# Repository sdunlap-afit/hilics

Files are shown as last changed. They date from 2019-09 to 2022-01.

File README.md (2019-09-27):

<div>
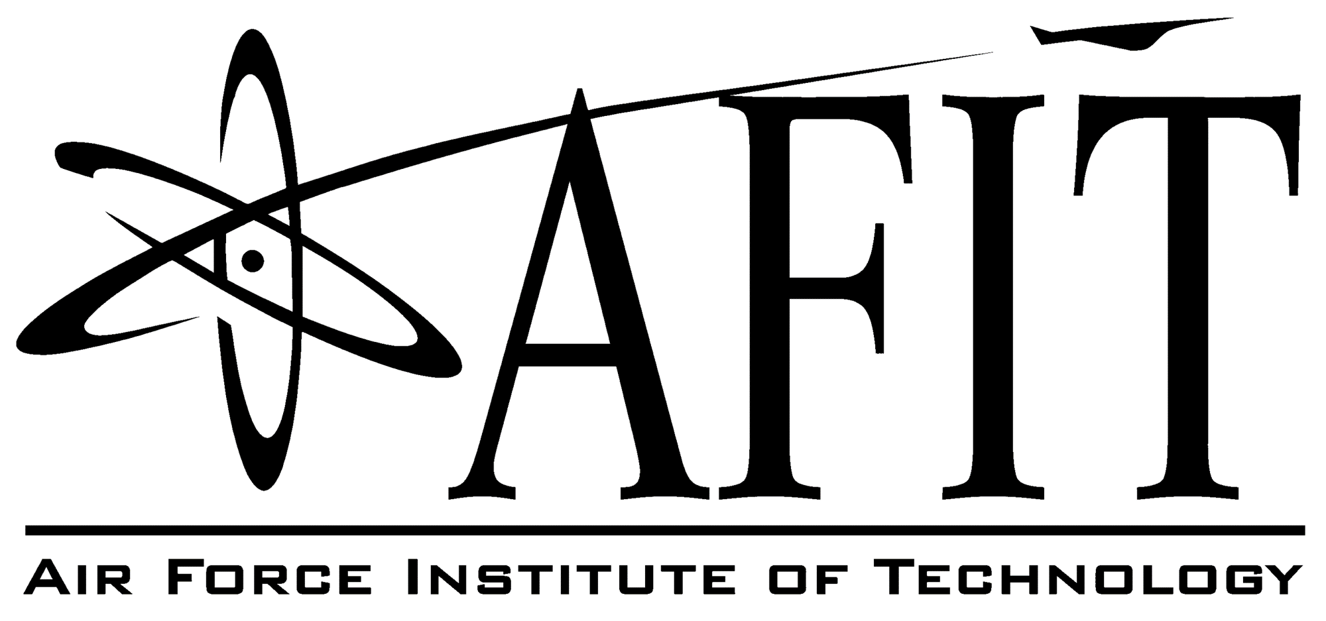
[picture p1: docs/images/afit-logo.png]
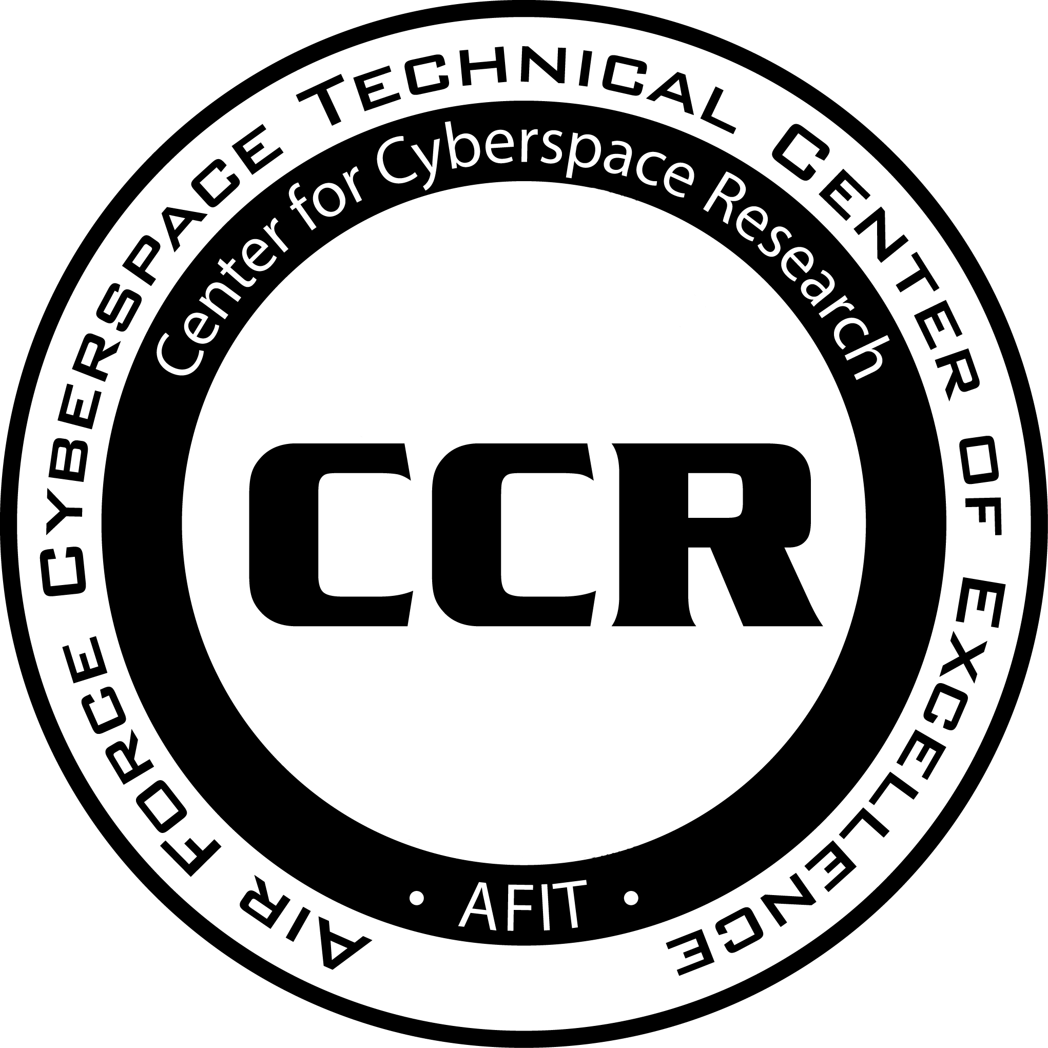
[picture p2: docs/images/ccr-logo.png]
  
</div>
<br clear="all" />
<br>

<div align="center">
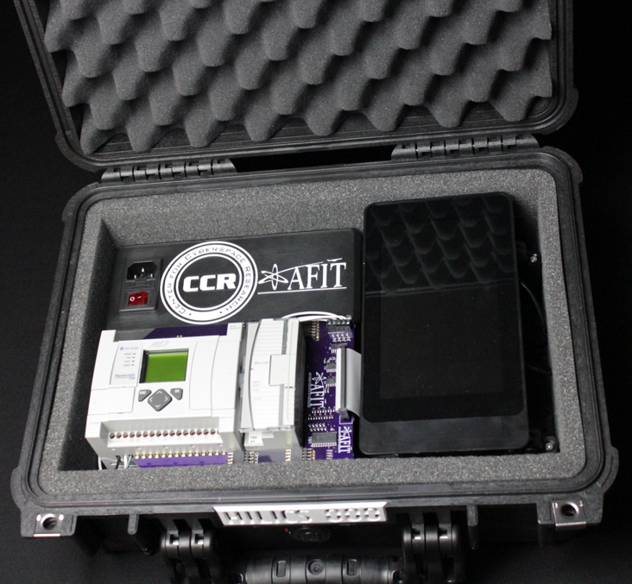
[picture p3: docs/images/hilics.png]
HILICS

</div>

# HILICS - Hardware-in-the-loop industrial control system training platform

The Center for Cyberspace Research (CCR) has conducted extensive research in Industrial Control System (ICS) security. ICS architectures utilize a variety of proprietary hardware and software configurations to control and monitor industrial processes and safety systems. Defenders must be familiar with the functionality, requirements and limitations of control systems in order to successfully defend them from cyber-attacks. Hands-on training and experience is crucial for defenders who must be able to interact safely with a given control system. Without this experience, defenders could mistakenly take actions that cause more harm to the system than a basic cyber-attack.  

Given the physical nature of ICS architectures, training platforms can be difficult and costly to develop. To address this, the CCR has developed HILICS - a unique hardware-in-the-loop ICS platform designed to support training, education and research. HILICS utilizes a MicroLogix 1100 Programmable Logic Controller (PLC) to introduce students to PLC operating basics and the associated programming languages. This PLC is a low-cost commercial product that provides a representative set of features to give students exposure to control system functionality. The HILICS platform is a custom hardware-in-the-loop system that enables trainers to incorporate multiple physical process simulations and expose students to a range of control system applications. The platform is designed to be flexible and scalable, allowing for varying class sizes and supporting various control system applications.  

# How it works

HILICS is a hardware-in-the-loop training system. A Raspberry Pi provides simulations of physical processes such as fluid tanks or garage doors. Each simulation is made up of sensors, actuators and physical components such as pipes or tanks. **The Raspberry Pi does not have any network connection to the PLC.**

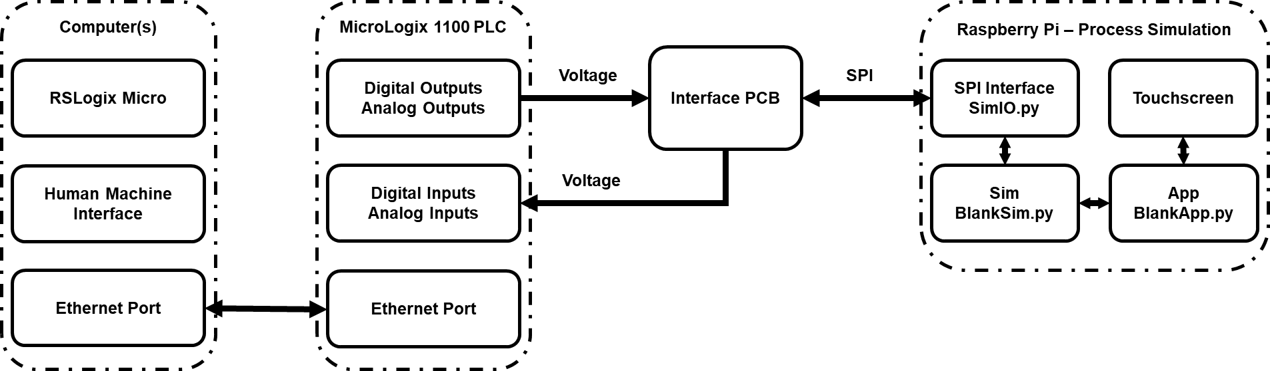
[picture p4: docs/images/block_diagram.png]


We will use the tank simulation as an example.

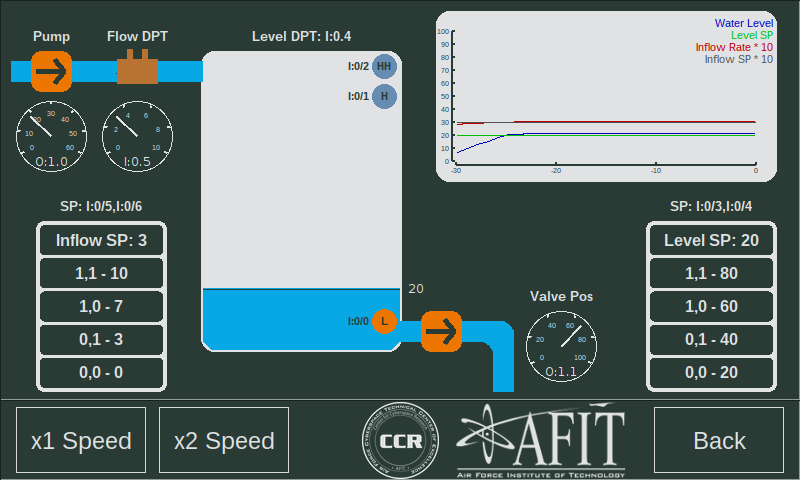
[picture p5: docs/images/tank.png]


## Sensors

The Raspberry Pi simulation determines the current state of the process and calculates the values of the simulated sensors. The sensor values are sent to the PLC via the interface PCB. The PLC receives these values as voltages using it's digital and analog inputs. The PLC's ladder logic program determines how the PLC responds to the sensor values.

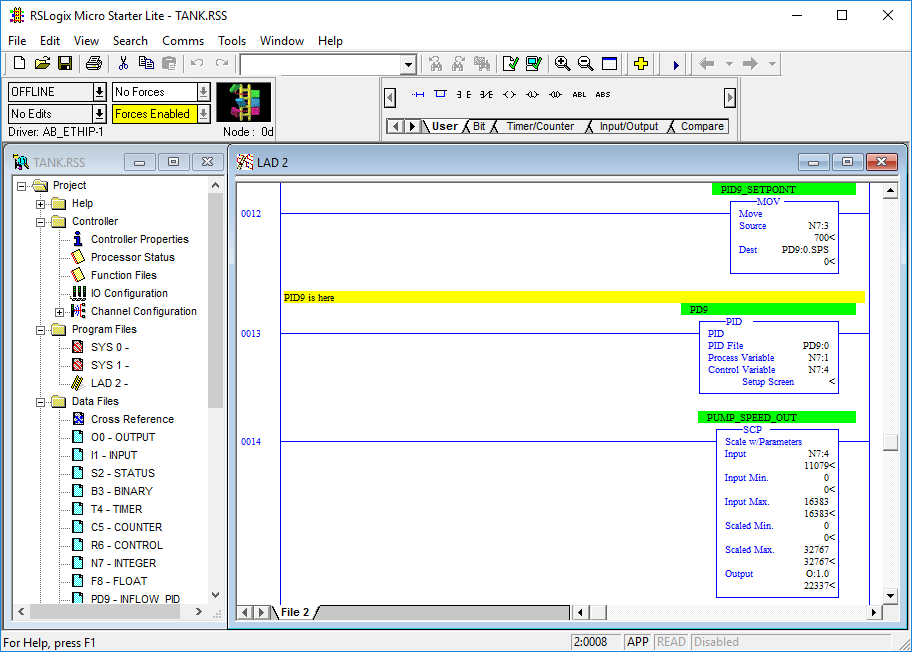
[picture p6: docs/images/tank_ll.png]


For the tank, there are two analog sensors and three digital sensors.

* Analog Sensors:
	* Inflow differential pressure transmitter.
	* Fluid level differential pressure transmitter.
* Digital Sensors:
	* Low level float
	* High level float
	* High-High level float
* Other:
	* This simulation was designed to work without the presence of an HMI. Typically, an HMI would be used to select set points for the process.
	* The Inflow SP button panel uses two of the PLC's digital inputs to send the desired inflow rate to the PLC.
	* The Level SP button panel uses two of the PLC's digital inputs to send the desired fluid level of the tank to the PLC.

## Actuators

The PLC reads the values of the sensors, compares them to the desired values and then adjusts it's outputs (as voltages) to control the actuators. The Raspberry Pi receives these values via the interface PCB and adjusts the simulation appropriately. 

For the tank, there are two analog actuators.

* Pump - the speed of the pump is used to calculate the current inflow rate into the tank.
* Valve - the position of the valve is used to calculate the outflow rate draining from the tank.

While the tank only has analog actuators, an example of a digital actuator is an indicator light controlled by the PLC's digital outputs.

Find further details about this simulation [here.](../labs/L3_Tank_Control.md)

# What's Included

## Documentation

The [docs](./docs) folder contains various documents including a bill-of-materials, hardware assembly and computer setup instructions.

## Source code

This repository contains all of the Python [source code](./src) you need to get started. The [apps](./src/apps) folder contains the following Applications:

* [IO_Test.py](./src/apps/IO_Test.py) - Basic app to test the functionality of the HILICS kit.
* [Door.py](./src/apps/Door.py) - Garage door simulation.
* [Fluid_Tank.py](./src/apps/Fluid_Tank.py) - Fluid tank with two control loops.
* [Blank_App.py](./src/apps/Blank_App.py) - A template to help you get started writing your own app.
* [Test_App.py](./src/apps/Test_App.py) - An app you can enable and edit to test your display elements during development.

## Hardware

The [hardware](./hardware) folder contains the design files and stl files you need to 3D print the frame for HILICS.

The [eagle](./hardware/eagle) folder contains all of the PCB design files and BOM.

## Labs

HILICS was designed for use in cyber security education, but the labs released here only cover basic PLC operations. Future labs may cover cyber concepts. 

The [labs](./labs) folder contains three basic labs to get started.

* [Lab 1](./labs/L1_Setup.md) - Get connected to your PLC and start programming in ladder logic.
* [Lab 2](./labs/L2_Door_Control.md) - Write a ladder logic program to control a garage door simulation.
* [Lab 3](./labs/L3_Tank_Control.md) - Learn the basics of PID control and PID tuning.

# Getting Started

## [Read the docs](./docs/README.md)

## [Try the labs](./labs/README.md)

## Contribute

This repository is not currently maintained and we will not be accepting any pull requests. If we develop any additional capabilities, we will release them here. If enough interest is shown, we might begin actively maintaining the repository. 

If you would like to contribute, look at the existing forks, or feel free to start your own.

# Disclaimer

Note that the views expressed in this project are those of
the authors and do not reflect the official policy or position of
the U.S. Air Force, U.S. Department of Defense or the U.S.
Government.

Approved for public release, 24 Sep 2019, Case #88ABW-2019-4607.

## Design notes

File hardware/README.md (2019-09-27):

<div>
HILICSHILICS  
</div>
<br clear="all" />
<br>

# Custom Hardware

## [Interface PCBs](./eagle/ML1100_Pi_Interface)

For each HILICS kit, you will need one each of the five [Interface PCBs](./eagle/ML1100_Pi_Interface). The bill of materials is in the folder with the PCBs. The BOM is for Digikey but provides specifications if you want to source components from a different supplier.

**You will also need 40-pin male headers for the Raspberry Pi ribbon cable to connect to the main PCB. These are cheaper on Amazon.**

If you plan to solder these by hand, make sure you are competent with surface mount soldering techniques. It may also be helpful to modify the main PCB design to use resistor arrays instead of individual resistors. Similar modifications can help reduce the amount of soldering required.

## [3D printing](./cad/stl_files)

The frame was designed in sections so that the largest part (135mm x 210mm) would still fit on a smaller 3D printer. 
We printed all of our components using black PLA without any supports. 
The amount of time and filament it will take depends heavily on your 3D printer settings.

 Our settings:

* 0.4mm layer height (0.2mm first layer height)
* 0.6mm nozzle
* 2 perimeters
* 3 bottom layers
* 3 top layers
* 20% infill

You will need to 3D print the following stl files (quantities listed):

* 1x - PLC Frame - 1x_HILICS_PLC_Frm.stl
* 2x - Raspberry PI Frame - 2x_HILICS_Pi_Frm.stl
* 2x - PCB legs - 2x_PCB_Leg.stl
* 3x - Extension Blocks - 3x_HILICS_ExtBlck.stl
* 1x - Choice of power box:
	* Multi-color: HILICS_Power_Color_* are individual stl files for multi-extruder/multi-color printers.
	* Single-color: HILICS_Power_single_ext.stl is for single extruder/color printers.

If you need to make modifications to the design, the Fusion 360 design files are [here.](./cad/Fusion360)

## [Nameplates](./cad/Nameplates)

You may also want to print [nameplates](./cad/Nameplates) for the front of your Pelican cases to uniquely identify each HILICS kit. We printed ours in white PLA

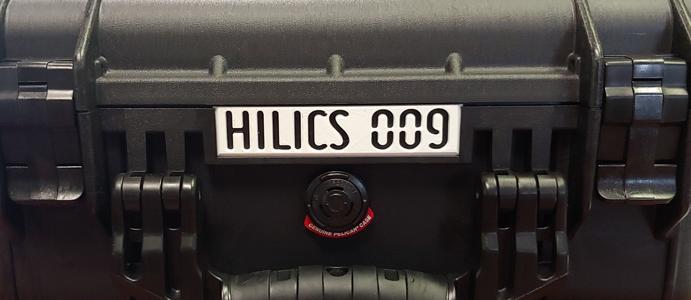
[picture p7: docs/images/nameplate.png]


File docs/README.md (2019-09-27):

<div>
HILICSHILICS  
</div>
<br clear="all" />
<br>

This guide will walk you through the steps to build your own HILICS training platform.

**WARNING: Building a HILICS kit is not for the faint-of-heart. Each HILICS kit costs roughly 1,000 USD to make (not counting labor), but your costs will vary. You will need to 3D print the frame, fabricate and solder the PCBs, wire 110 VAC power to the PLC, and setup a Raspberry Pi running Rasbian.**

# Components - BOM

## MicroLogix 1100 PLC
HILICS is designed to work with the MicroLogix 1100 PLC. The specific model number for the PLC and the Analog Output module are listed below. 

**NOTE: HILICS does not currently support any other PLC or PLC configuration. Other versions of the MicroLogix 1100 may work, but modifications will be needed.**

* 1763-L16BWA - MicroLogix 1100 with:
	* 9 digital inputs
	* 6 relay outputs
	* 2 analog inputs
	* 110 VAC power input

* 1762-OF4    - Module with 4 analog outputs

## [Raspberry Pi](https://www.raspberrypi.org/)

HILICS is designed around the Raspberry Pi for running process simulations.

For each HILICS kit, you will need the following Raspberry Pi components:

* Raspberry Pi from the list below.
* Official Raspberry Pi 7" touch screen display.

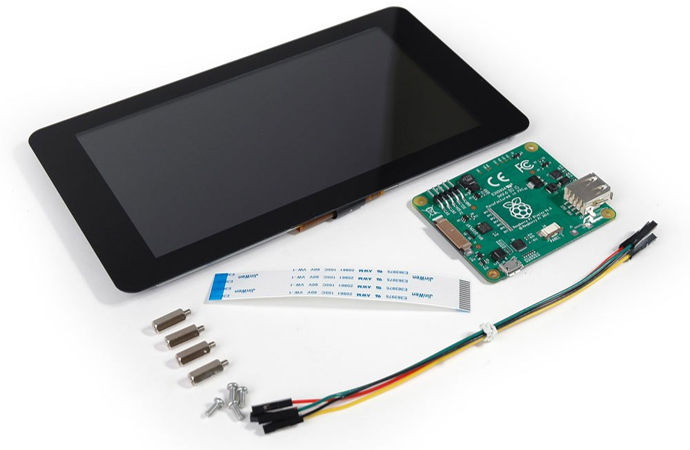
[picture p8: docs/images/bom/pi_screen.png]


* SmartiPi case for the official Raspberry Pi 7" touch screen Display.

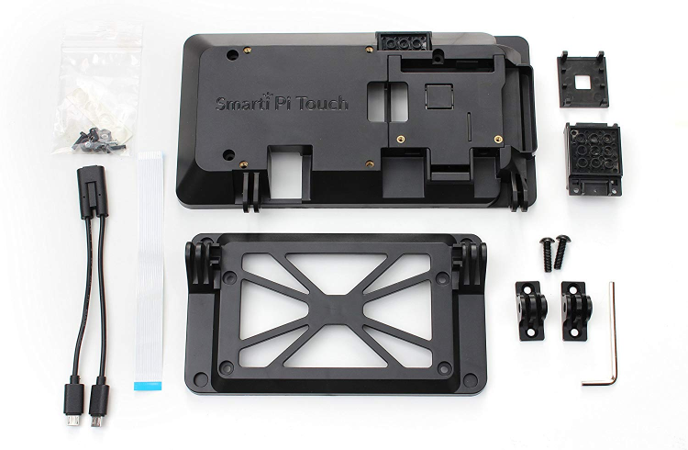
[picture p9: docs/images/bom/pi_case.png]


* 40-pin (2 row) male header (for main HILICS PCB).
* The following components may come as part of a Raspberry Pi kit (e.g., CanaKit)
	* 40-pin GPIO ribbon cable for Raspberry Pi.
	* Micro SD card.
	* Raspberry Pi power supply (5V 2.5A).
	* Optional, but recommended - Raspberry Pi heatsinks

Tested:
* Raspberry Pi 3 B 
* Raspberry Pi 3 B+

Untested, but should work:
* Raspberry Pi 4

Not recommended
* Raspberry Pi 2 or prior
* Raspberry Pi Zero or similar

## [Pelican 1450](https://www.pelican.com/us/en/product/cases/protector/1450)

The HILICS frame was designed to fit inside a Pelican 1450 case with the "Pick N'Pluck" foam removed.

Other cases may work (with modifications), but we recommend you look at the dimensions in the Fusion 360 files before purchasing a case.

## Power connectors

These are generic parts that are cheap and readily available. Purchase one to verify it will fit in the 3D printed power box. If the power box is too tight, you may need to use a knife to trim away some plastic.

Each HILICS kit requires:
* One 110 VAC panel mount outlet
* One panel-mount power socket with fuse and switch

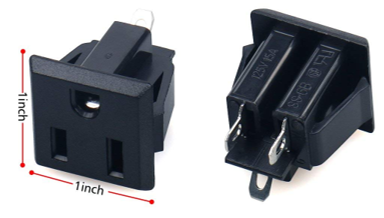
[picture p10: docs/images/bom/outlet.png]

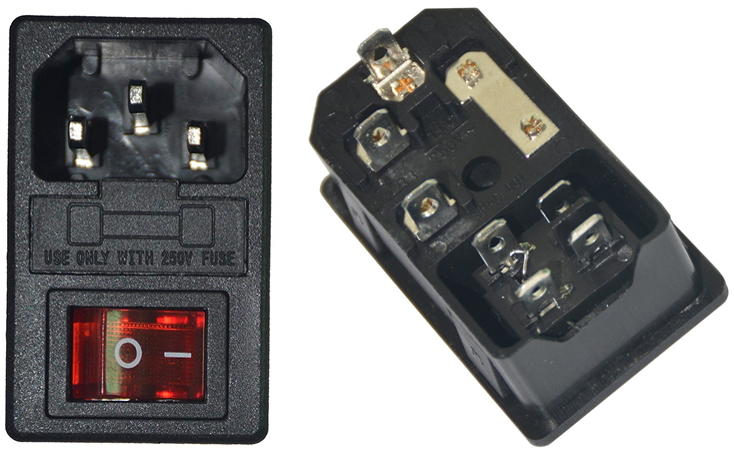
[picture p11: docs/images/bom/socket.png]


## Other components

* M3x8mm countersunk bolts/screws.
* M3x12mm countersunk bolts/screws.
* M3x10mm pan head bolts/screws (longer will also work).
* M3 nuts.
* M4x8mm pan head bolts/screws (longer will also work).
* 22 AWG stranded wire.
* 18 AWG stranded wire.
* Spade connectors, strippers and crimpers

## [Interface PCBs](../hardware/eagle/ML1100_Pi_Interface)

For each HILICS kit, you will need one each of the five [Interface PCBs](../hardware/eagle/ML1100_Pi_Interface). The BOM is in the folder with the eagle files. The BOM is for Digikey but provides part numbers if you want to source components from a different supplier.

**You will also need 40-pin male headers for the Raspberry Pi ribbon cable to connect to the main PCB. These are cheaper on Amazon.**

If you plan to solder these by hand, make sure you are competent with surface mount soldering techniques. It may also be helpful to modify the main PCB design to use resistor arrays instead of individual resistors. Similar modifications can help reduce the amount of soldering required.

## [3D printing](../hardware/cad)

The frame was designed in sections so that the largest part (135mm x 210mm) would still fit on a smaller 3D printer. We printed all of our components using black PLA without any supports. 
The amount of time and filament it will take depends heavily on your 3D printer settings.

 Our settings:

* 0.4mm layer height (0.2mm first layer height)
* 0.6mm nozzle
* 2 perimeters
* 3 bottom layers
* 3 top layers
* 20% infill

You will need to 3D print the following stl files (quantities listed):

* 1x - PLC Frame - 1x_HILICS_PLC_Frm.stl
* 2x - Raspberry PI Frame - 2x_HILICS_Pi_Frm.stl
* 2x - PCB legs - 2x_PCB_Leg.stl
* 3x - Extension Blocks - 3x_HILICS_ExtBlck.stl
* 1x - Choice of power box:
	* Multi-color: HILICS_Power_Color_* are individual stl files for multi-extruder/multi-color printers.
	* Single-color: HILICS_Power_single_ext.stl is for single extruder/color printers.

If you need to make modifications to the design, the Fusion 360 design files are [here.](../hardware/cad/Fusion360)

## [Nameplates](../hardware/cad/Nameplates)
You may also want to print [nameplates](../hardware/cad/Nameplates) for the front of your Pelican cases to uniquely identify each HILICS kit. We printed ours in white PLA



# Assembly

## [Raspberry Pi setup](./RPi_Setup.md)

## [Hardware assembly](Hardware_Assembly.md)

## PLC setup

1. [Install Rockwell Tools](./Rockwell_Tools.md)
1. [Configure PLC network settings](./PLC_Net_Config.md)
1. [Configure RSLinx](./RSLinx_Config.md)
1. [Configure RSLogix project](./RSLogix_Net_Config.md)

## [Hardware test](./Hardware_Test.md)

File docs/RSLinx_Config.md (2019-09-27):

<div>
HILICSHILICS  
</div>
<br clear="all" />
<br>

# RSLinx setup 

RSLinx is a utility that facilitates communication between RSLogix Micro and Rockwell PLCs. In order for RSLogix to talk to the PLC, RSLinx must first be configured.

**Before you begin this guide, make sure that [RSLinx is installed](./Rockwell_Tools.md) and that you can ping the MicroLogix 1100.**

1. Open RSLinx and click the RSWho icon.

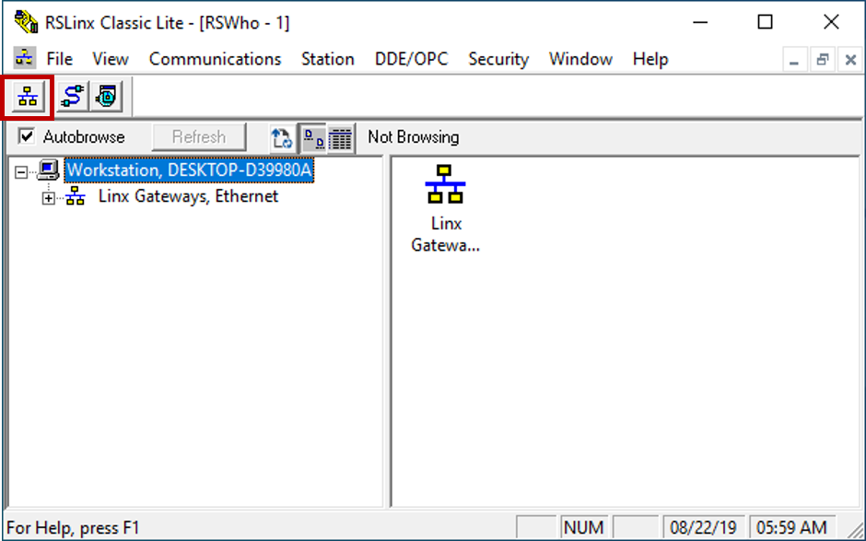
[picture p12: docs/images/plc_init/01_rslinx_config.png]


2. Click "Communications >> Configure Drivers..."

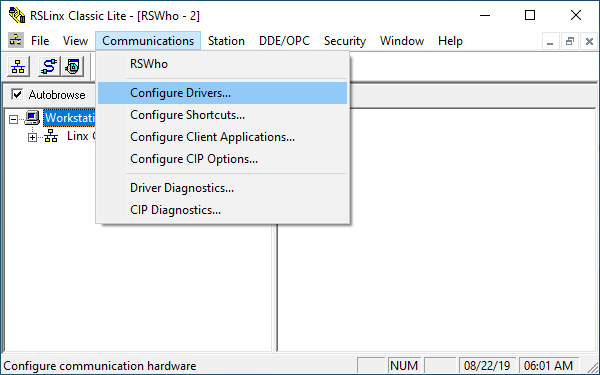
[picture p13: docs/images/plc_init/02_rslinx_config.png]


3. In the Configure Drivers window, select "EtherNet/IP Driver" from the dropdown menu.

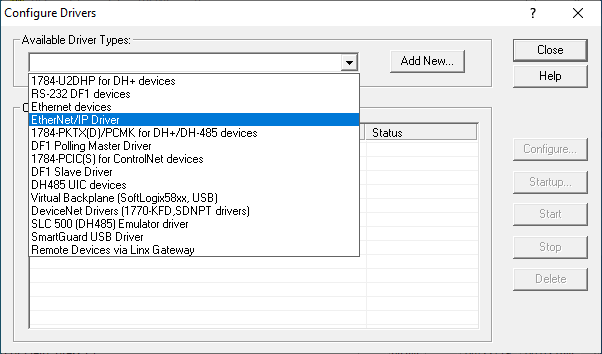
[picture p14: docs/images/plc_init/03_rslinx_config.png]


4. Click "Add New".

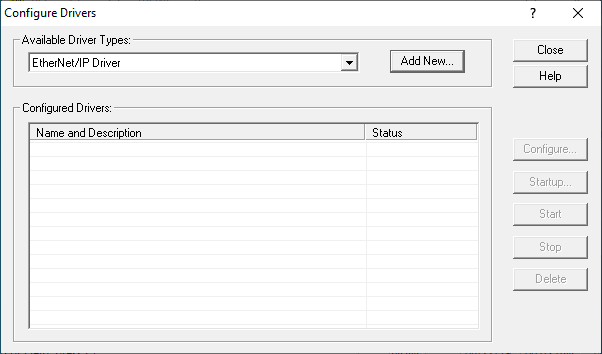
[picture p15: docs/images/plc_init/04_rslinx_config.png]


5. You can rename the driver if you like, but the default name is fine. Click "OK".

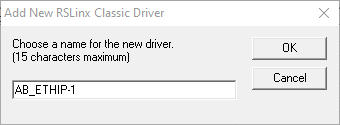
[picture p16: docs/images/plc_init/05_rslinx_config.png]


6. In the new window, choose "Browse Local Subnet" and select the network interface that is connected to the PLC or the PLC network. 

	Click "OK".

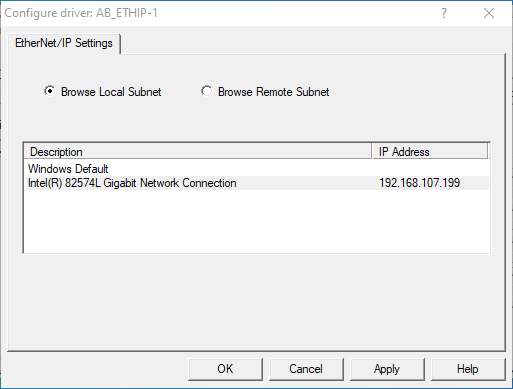
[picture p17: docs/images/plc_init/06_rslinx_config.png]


7. If all goes well, RSLinx should automatically find your PLC and add it to the device list under the driver. This process may take some time depending on your subnet configuration.

	Note: As long as this window is open, RSLinx will browse your subnet looking for new PLCs.

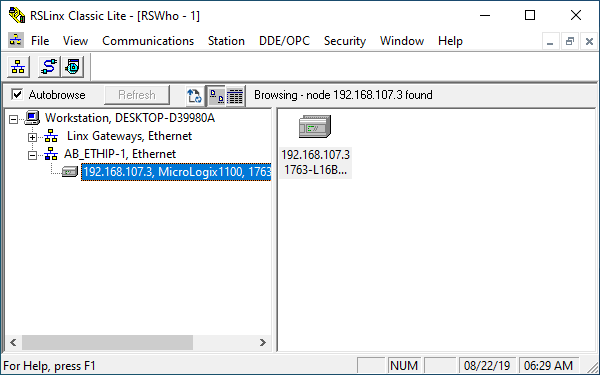
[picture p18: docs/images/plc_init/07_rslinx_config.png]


<br><br><br>

Previous: [Configure PLC network settings](./PLC_Net_Config.md)

Return: [Build a kit](./README.md)

Next: [Configure RSLogix project](./RSLogix_Net_Config.md)

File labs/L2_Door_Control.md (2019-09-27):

<div>
HILICSHILICS  
</div>
<br clear="all" />
<br>

# Lab 2 - Door Control

# Intro

During this lab you will learn about programming PLCs using ladder logic. In order to demonstrate this, you will write a fully functioning door controller. All of the control in this lab is digital (i.e., no analog inputs or outputs used).

# Understanding the simulation

First, let's take a look at the door simulation to understand the individual components.

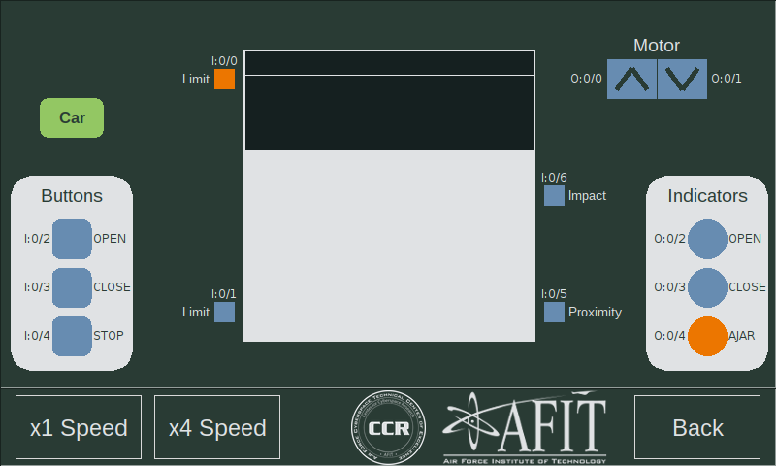
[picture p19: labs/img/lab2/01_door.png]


## Sensors:

* **Buttons:** the button panel allows the user to operate the door. Pressing one of the buttons on the touchscreen toggles the state of that button and the value is sent to the corresponding PLC digital input. The PLC must read these values and determine how to react. **Multiple buttons may be pressed at one time.**

* **Limits:** the limit switches are used to detect if the door is fully open, fully closed or somewhere in between (ajar). If the door is fully closed, Limit I:0/1 will be high (orange). If the door is fully open, Limit I:0/2 will be low (blue). **Note the inverted logic between these two - this was intentional.**

* **Proximity:** this sensor detects the presence of a car driving through the door.
* **Impact:** this sensor detects if the door impacts a car.

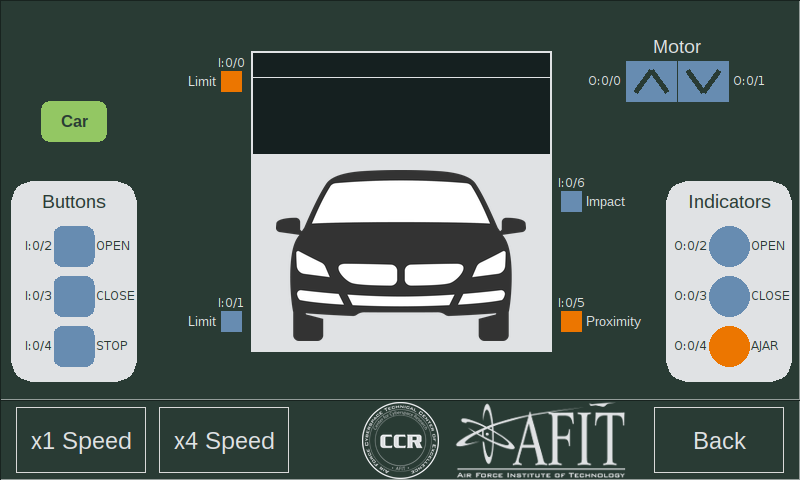
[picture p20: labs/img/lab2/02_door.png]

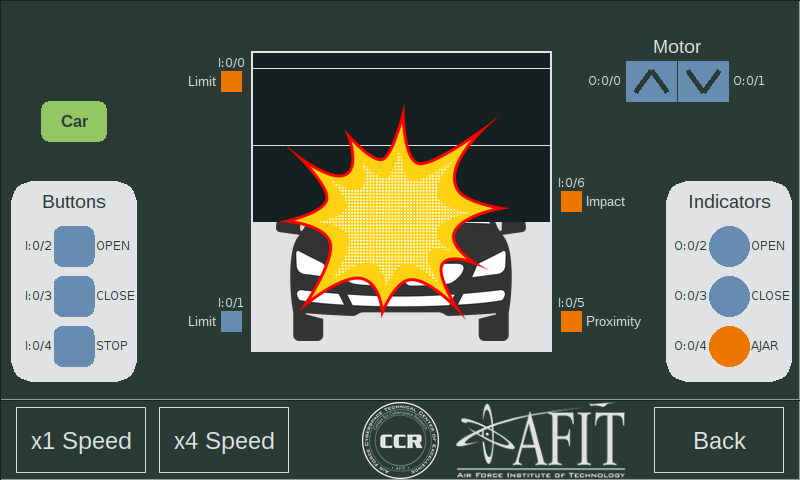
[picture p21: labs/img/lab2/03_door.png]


## Actuators:

* **Motor:** To simplify the control scheme, the door simulation uses two Relay Outputs from the PLC to control the Motor. O:0/0 tells the motor to move the door up, and O:0/1 tells the motor to move the door down.

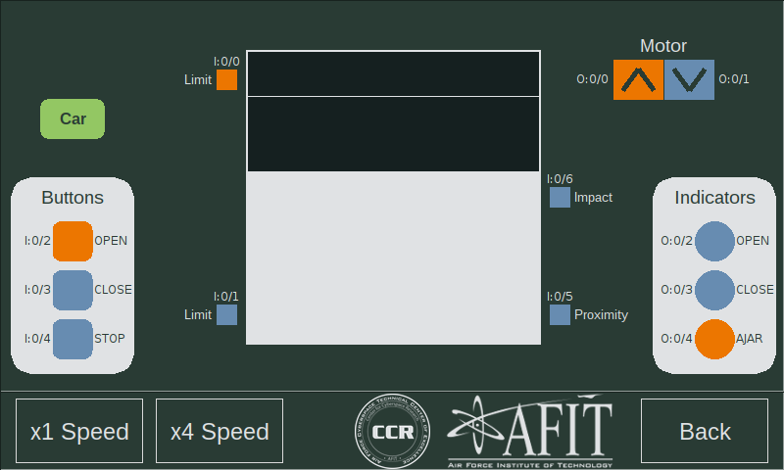
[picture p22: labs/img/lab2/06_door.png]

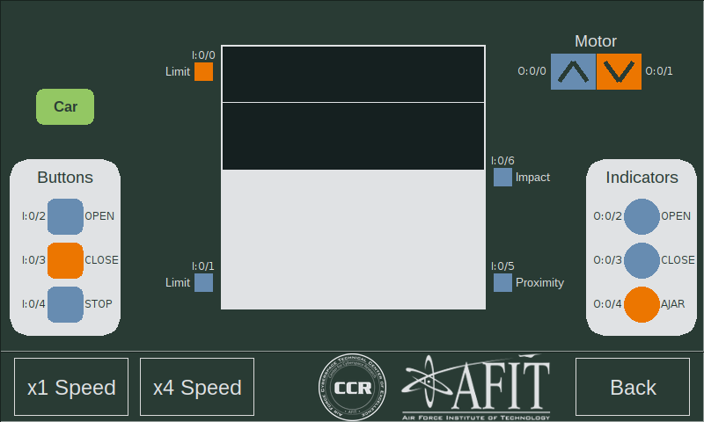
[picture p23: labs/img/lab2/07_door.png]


* **Indicators:** There are three indicator lights controlled by the PLC via three Relay Outputs. 
	* "OPEN" (O:0/2) indicates that the door is fully open.
	* "CLOSE" (O:0/3) indicates that the door is fully closed.
	* "AJAR" (O:0/4) indicates that the door is neither fully open nor closed.

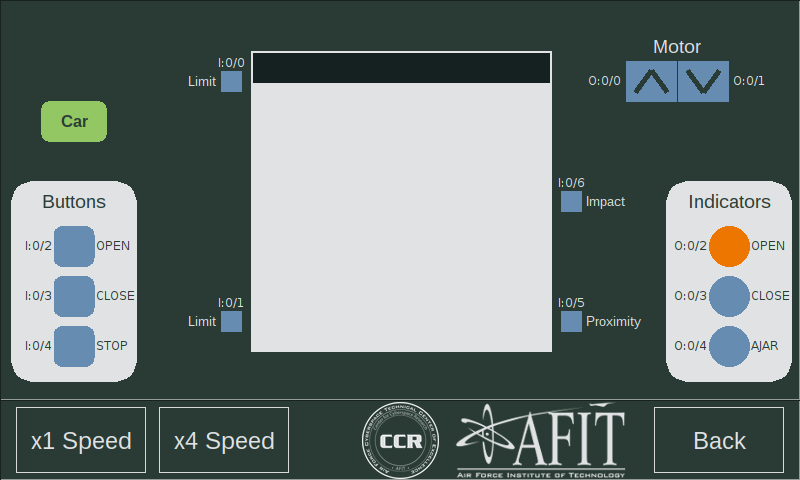
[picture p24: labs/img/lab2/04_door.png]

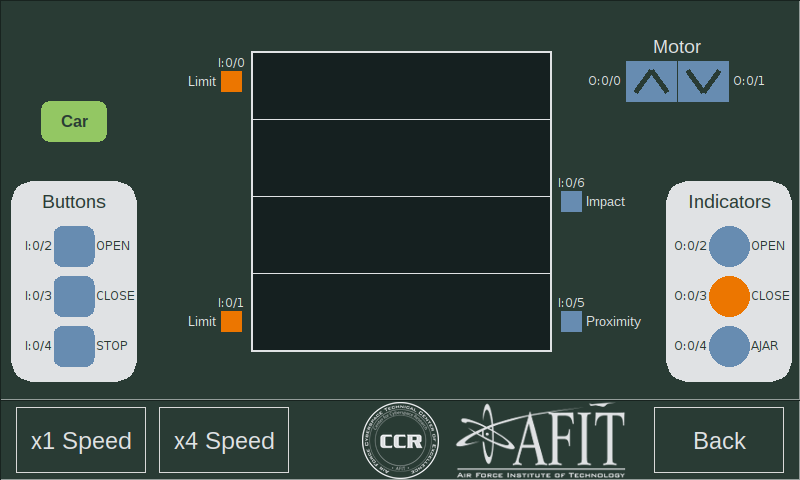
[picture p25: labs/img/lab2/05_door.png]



## Other:

* **Speed Control:** testing different ladder logic code can get tedious if the door takes too long to open or close. Pressing the "x4 Speed" button will speed up the simulation by a factor of 4. Pressing the "x1 Speed" button will return the simulation to normal time.

* **Car:** pressing the "Car" button will cause a simulated car to drive through the door. The car will remain present for 10 seconds and then disappear. Pressing the button multiple times will reset the 10 second timer allowing the car to stay longer.

* **Alarm:** the "ALARM!" warning will display momentarily if the motor is driven in both directions simultaneously or if the motor quickly reverses direction. 
	
	Note: if the simulation is running at 4x speed, it may be difficult to get the alarm to show the motor reversing directions.

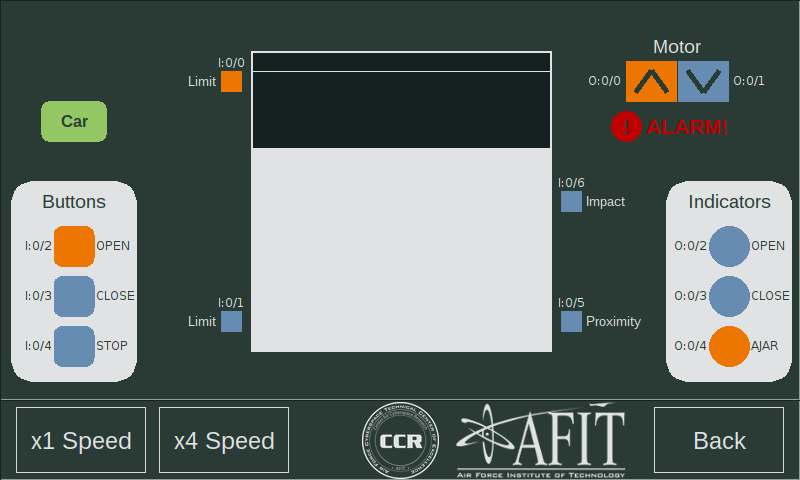
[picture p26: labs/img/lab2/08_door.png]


# Instructions

1. **Make a copy of IO_Test.RSS** and use it as a baseline to get started on this project.

	**Warning! If you start with a blank project file, you must [configure the network settings](../docs/RSLogix_Net_Config.md) so that you do not remove your PLC's IP address assignment.**

1. Write a ladder logic program that fulfills the following criteria:

	1. The motor must never be driven both up and down at the same time.
	
	1. The PLC must activate the appropriate indicator for the current state of the system. Only one indicator should be active at a time.
	1. The “OPEN” and “CLOSE” buttons should work when they are activated.
	1. If the “OPEN” and “CLOSE” buttons are both active the door should stop.
	1. When the “STOP” button is pressed, the door should stop.
	1. When the door reaches a limit switch it should stop.
	1. When the “Proximity” sensor is triggered, the door should not be able to move down, but may continue to move up. This is to avoid crashing into a car.
	1. If the “Impact” sensor is triggered, the motor should stop completely.

1. If time permits, add logic to the program to enforce one final criteria. 

	- The motor must not reverse direction until it has come to a complete stop first. 

	Since no feedback is available, a timer may be used to delay 2 seconds before reversing direction. This should provide enough time for the door to stop fully.

	Note: See [this tutorial](https://www.youtube.com/watch?v=kONl5e9f6Qk) for an example of using timers in RSLogix 500:

<br><br>
[Return](./README.md)

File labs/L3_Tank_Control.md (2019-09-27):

<div>
HILICSHILICS  
</div>
<br clear="all" />
<br>

# Lab 3 - Fluid Tank Control

# Intro

During this lab you will learn about PID control and tuning. In order to demonstrate this, you will modify the existing Tank.RSS project file to tune the PID for controlling the fluid inflow into the tank.

# PID Control

PID controllers are extremely common tools for controlling analog physical processes. For example, quad-copters use 3 or more PIDs to vary the speed of the 4 propellers to achieve specific yaw, pitch and roll values and stay in the air. 

PID stands for “proportional–integral–derivative” and has three primary tuning parameters: P, I and D. 

Read the summary and fundamental operation of PID controllers [here](https://en.wikipedia.org/wiki/PID_controller) to get a general idea of how they work.

**PIDs function by measuring a “Process Variable” (PV), calculating error based on a “Setpoint” (SP) and using the error and PID tuning parameters to calculate a “Control Variable” (CV).**

The fluid tank uses two PID controllers:
* Inflow rate PID - PD9:
	* PV - Inflow rate
	* CV - Pump speed
* Fluid level PID - PD10:
	* PV - Fluid level
	* CV - Valve position

# Understanding the simulation

In this lab, you will use the Fluid Tank simulation to experiment with PIDs. 

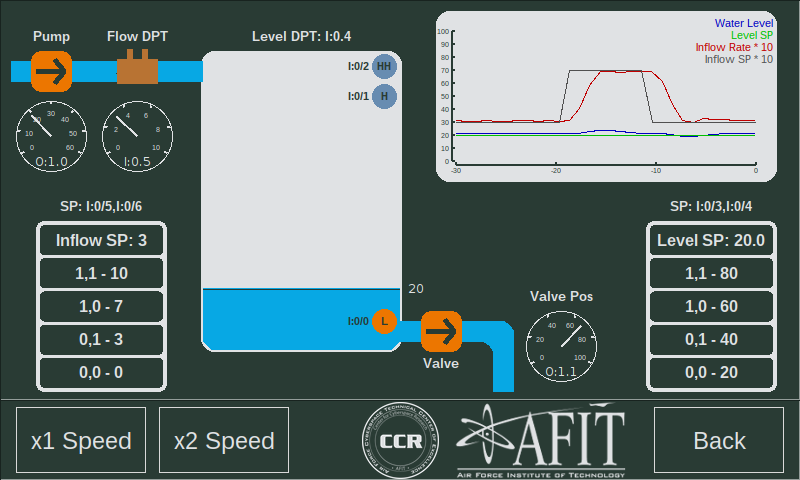
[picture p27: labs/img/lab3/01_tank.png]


## Actuators

This simulation uses two actuators. Each actuator has an analog output to determine the position/speed and a digital output to enable/disable the actuator. If the actuator is disabled it will return to 0.

* Pump
	* Enable - Digital output 0 - O:0/0
	* CV - Analog output 0 - O:1.0
		* Min - 0V (0) - pump idle
		* Max - 10V (32767) - 10% of the tank level per second
* Valve
	* Enable - Digital output 1 - O:0/1
	* CV - Analog output 1 - O:1.1
		* Min - 0V (0) - 10% of the tank level per second
		* Max - 10V (32767) - valve closed

## Sensors

This simulation has two analog sensors and three digital sensors. The two analog sensors represent differential pressure transmitters (DPTs).

* Flow DPT
	* Analog input 1 - I:0/5
	* Min - 0v (0) - 0 flow
	* Max - 10V (1023) - 10% of the tank level per second
* Fluid level DPT
	* Analog input 0 - I:0/4
	* Min - 0v (0) - tank empty
	* Max - 10V (1023) - tank full 
* Float sensors (not used in lab)
	* Low - I:0/0 - threshold 10%
	* High - I:0/1 - threshold 85%
	* High-high - I:0/2 - threshold 95%

## Other

### **Setpoint selection**

This simulation was designed to work without the presence of an HMI. Typically, an HMI would be used to select setpoints for the process. Instead, the simulation uses digital inputs of the PLC to send setpoints. The PLC must interpret these values.
	
The Inflow SP button panel uses two of the PLC's digital inputs to send the desired inflow rate to the PLC.

| Inflow Setpoint | I:0/5 | I:0/6 |
|:---:|:-----:|:-----:|
| 0 | 0 | 0 |
| 3 | 0 | 1 |
| 7 | 1 | 0 |
| 10 | 1 | 1 |

The Level SP button panel uses two of the PLC's digital inputs to send the desired fluid level to the PLC.

| Level Setpoint | I:0/3 | I:0/4 |
|:---:|:-----:|:-----:|
| 20 | 0 | 0 |
| 40 | 0 | 1 |
| 60 | 1 | 0 |
| 80 | 1 | 1 |

### **Graph**

To assist the PID tuning process, the simulation includes a plot of the relevant data. Touching/clicking on the graph will enlarge it. Touching it again will return it to normal size. The graph is implemented as a widget in the src/widgets/ directory for use in other apps.

### **Speed selection**

You can speed up the simulation by clicking the "x2 Speed" button. **Warning: speeding up the simulation will change the required PID tuning parameters.**

# Instructions

## Getting Started

1. Open the Tank project file in RSLogix.

2. Find the PID block for PD9:0.

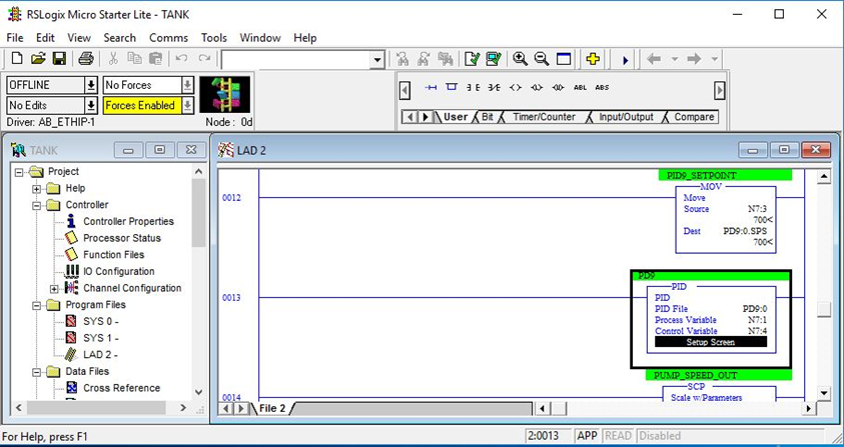
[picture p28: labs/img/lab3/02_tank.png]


3. Open the PID “Setup Screen” and verify that it looks like this. All of the values under Tuning Parameters and most of the Flags should be the same. Under "Inputs" and "Outputs" SPS, PV and CV may be different, but the max and min values should be the same.

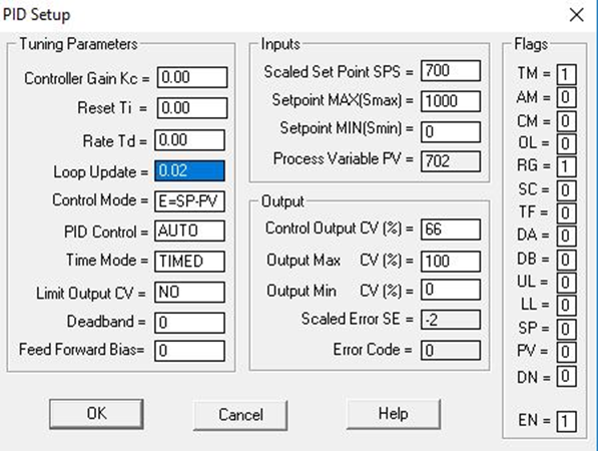
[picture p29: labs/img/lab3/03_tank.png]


## Tuning:

1. PID tuning is the process of selecting the three tuning parameters to achieve optimal results. PID tuning is 1% science, 9% art and 90% random guessing.

2. You will tune PID9 to accurately control the pump to achieve a specific inflow rate.

3. Each time you change the tuning parameters, change the "Inflow SP" to 3, wait for it to stabilize, and then change it to 7. Pay attention to how the Inflow Rate responds to the Inflow SP with different tuning parameters.

4. **Start by increasing P while keeping I and D at 0.0. Notice how the process responds to SP changes.**

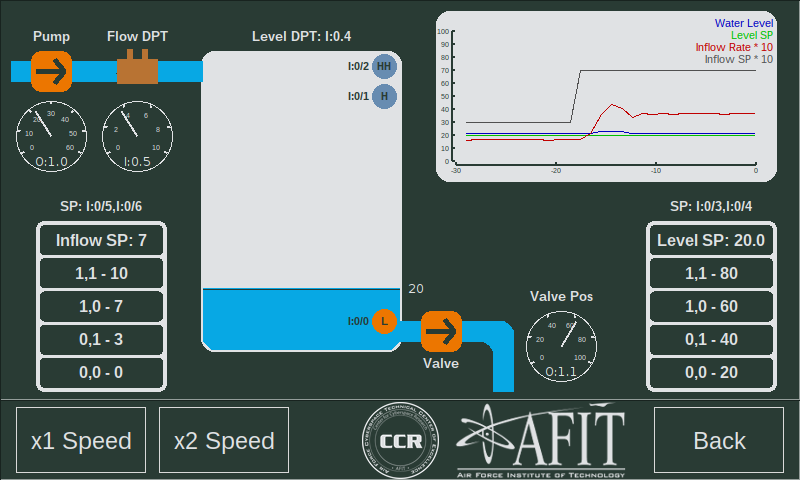
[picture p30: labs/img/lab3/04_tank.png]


5. **Next, add I. In this program, the smaller the I-value, the larger the impact. Start with an I of 0.10 and decrease it to see the impact.**



6. **Lastly, add in some D to reduce the overshoot. Note how the system reacts when you have too much D vs too little D. Also note how CV behaves as you change D.**



<br><br>
[Return](./README.md)

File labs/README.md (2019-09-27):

<div>
HILICSHILICS  
</div>
<br clear="all" />
<br>

# Labs

These are basic example labs to get you started. Hopefully more will be coming soon.

## [Lab 1 - Setup and familiarization](./L1_Setup.md)

## [Lab 2 - Door Control](./L2_Door_Control.md)

## [Lab 3 - Fluid Tank Control](./L3_Tank_Control.md)

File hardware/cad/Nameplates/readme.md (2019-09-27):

# Overview
The purpose of this project is automatic generation of nameplates for the Hardware-in-the-loop Industrial Control System training kit. The project uses Python and OpenSCAD to generate the models.



# Installation
## OpenSCAD
### Download
  * http://www.openscad.org/downloads.html
  * For Windows: grab the exe installer to make it easier to install
### Install
  * Run the installation program
  * Add the OpenSCAD program to your PATH environment variable
## Python
### Download
  * https://www.python.org/downloads/
  * Get Python 3.7 
### Install
  * Run the installer
    * Make sure the Add to PATH option is selected.  Otherwise you will need to manually add Python to your PATH environment variable.
  * Open a command line interface (CLI)
    * On Windows run cmd.exe or powershell as administrator
    * Run the following commands:
      ```bash
      pip install -U pip
      pip install pipenv
      ```
## Fonts
  * Find fonts in the fonts directory
  * Select the font files, right-click and select Install
## Project
  * Once OpenSCAD and Python are installed you can setup the project.
  * Open a CLI in the project workspace.
  * Use pipenv to install the necessary libraries
    * pipenv installs libraries according to the Pipfile
    ```bash
    pipenv install
    ```
# Running
## Configuration
There is a configuration section at the top of `nameplates.py`. You can configure how many ids make, rough size of the nameplate, and the text and font.
## Run the script
You can run the python script in the development environment of your choice.  Or you can run the script with the following CLI command.  `pipenv shell` activates the python virtual environment used by the `nameplates.py` script.
```bash
pipenv shell
python nameplates.py
```

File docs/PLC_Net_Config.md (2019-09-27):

<div>
HILICSHILICS  
</div>
<br clear="all" />
<br>

# How to assign an IP address to your PLC

**NOTE: Many of the labs and example ladder logic applications assume that the IP address of the PLC is 192.168.107.3. We recommend you use this IP if possible.**

1. Launch "BOOTP-DHCP Server"

2. Wait for your PLC's MAC address to show up with BOOTP listed under "Type".

	* If the PLC doesn't show up after a minute, use the buttons on the PLC to see if it already has an IP address. 
	* If it does not have an IP address, double-check your ethernet connections.



3. Select your PLC in the "Recent History" list and click "Add to Relation List".

4. Enter your desired IP address and click "OK".



5. Your PLC's MAC address and IP address will now show up under "Relation List". 

	**Initially, the "Type" field will be blank - this means that the IP address has not yet been assigned to the PLC. You must wait until "BOOTP" is listed under "Type" as shown below. This indicates that the PLC's IP address has been assigned.**



6. At this point, the PLC has an IP address, but is still configured to use BOOTP when booting up. If you power-cycle the PLC, it will lose it's IP address and you will need to repeat this process.

7. Make sure your computer's IP address is in the same subnet as the PLC. **You should be able to ping the PLC at this point.**

8. To disable BOOTP and make the IP address permanent, select your PLC under "Relation List" and click "Disable BOOTP/DHCP". If this command works, you will see "[Disable BOOTP] Command Successful" under "Status" at the bottom of the window.



9. It is now safe to close BOOP/DHCP Server and power-cycle the PLC.

<br><br><br>

Previous: [Install Rockwell Tools](./Rockwell_Tools.md)

Return: [Build a kit](./README.md)

Next: [Configure RSLinx](./RSLinx_Config.md)

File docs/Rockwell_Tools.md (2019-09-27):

<div>
HILICSHILICS  
</div>
<br clear="all" />
<br>

# RSLogix Micro Starter Lite download

HILICS is designed to support the MicroLogix 1100 PLC. The programming software for this PLC (RSLogix Micro Starter Lite) is free! Follow this brief guide to get the software ready for your MicroLogix 1100.

1. To download software from Rockwell, you will need to create a free account. 

2. Follow [this guide to download RSLogix Micro Starter Lite](https://rockwellautomation.custhelp.com/app/answers/details/a_id/63956/~/where-can-i-find-rslogix-micro-starter-lite-software%3F).

# RSLinx download

1. While you are on the "Compatibility & Downloads" page, search for "RSLinx". Select the free version and click the download button on the right. 



2. Select the latest version and click "Downloads". Follow the prompts to download the installer for RSLinx.



# Install

1. Install both RSLogix and RSLinx on a Windows computer (XP, Win 7 or Win 10). I recommend creating a virtual machine for this. 

	You will need to run the downloaded executables and extract any ZIP files. Eventually you should find a "setup.exe" file for each program. Run these two files to install the tools.

	The installation process is pretty straight forward and you can keep all the default settings for the installers.

2. At this point you should see a "Rockwell Software" folder in your start menu. Three of these applications are needed to move forward:

	* BootP-DHCP Tool
	* RSLinx Classic
	* RSLogix Micro

 

<br><br><br>

Previous: [Hardware assembly](./Hardware_Assembly.md)

Return: [Build a kit](./README.md)

Next: [Configure PLC network settings](./PLC_Net_Config.md)

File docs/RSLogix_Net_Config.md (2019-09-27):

<div>
HILICSHILICS  
</div>
<br clear="all" />
<br>

# IP address setting in RSLogix

In RSLogix Micro Starter Lite, each project has it's own network configuration. During a Download, if the network configuration in the project doesn't match the PLC's configuration, RSLogix will prompt you to "Apply" or "Don't Apply" the project's settings. By default, BOOTP is enabled in the project configuration; you will need to change this so that your PLC's IP address doesn't get wiped out each time you do a Download.

Note: you can also use this method to change the PLC's IP address.

1. Open [DEMO.RSS](../labs/LadderLogic_Examples/) (or other project file) in RSLogix.

2. In the tree on the left, double-click "Channel Configuration".



3. In the new window, select Channel 1 tab.

4. Fill out the highlighted fields to match your desired settings. **Remember to deselect "BOOTP Enable".** Click "OK" to close this window.



5. Click the arrow next to "OFFLINE" and click "Download".



6. If all goes well, you should see the following window. Click "Yes" to continue. 

	**If RSLogix/RSLinx fails to find the PLC, try step 10 below.**



7. If the project network settings don't match the PLC's settings, you will see this window. To apply the project settings to the PLC, click "Apply". 

	**If you are not sure that your project settings are correct, click "Don't Apply"**



8. Once the settings are applied, you may need to repeat the Download (Steps 5 and 6 above). If the Download completes successfully, you should see "REMOTE PROG" or "REMOTE RUN".



9. If it's in "REMOTE PROG", click the arrow again and select "Run". This will put the PLC in run mode and your Ladder Logic will begin executing.



## **If steps 5 & 6 above don't work:**

10. Select "Comms >> System Comms".



11. In the "Communications" window, expand AB_ETHIP-1 driver and select your PLC from the list.

	Click "Download" on the right.

	Go back to Step 6 to continue.



<br><br><br>

Previous: [Configure RSLinx](./RSLinx_Config.md)

Return: [Build a kit](./README.md)

Next: [Hardware test](./Hardware_Test.md)

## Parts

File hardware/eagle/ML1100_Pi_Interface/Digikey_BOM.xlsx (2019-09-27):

Manufacturer Part Number | Manufacturer | Digi-Key Part Number | Quantity | Description
61301421021 | Wurth Electronics Inc. | 732-5355-ND | 2 | CONN HEADER R/A 14POS 2.54MM
M20-9700545 | Harwin Inc. | 952-3270-ND | 2 | CONN HEADER R/A 10POS 2.54MM
OSTTE050104 | On Shore Technology Inc. | ED2743-ND | 1 | TERM BLK 5POS SIDE ENT 3.5MM PCB
PPPC072LJBN-RC | Sullins Connector Solutions | S5560-ND | 2 | CONN HDR 14POS 0.1 GOLD PCB R/A
PPPC052LJBN-RC | Sullins Connector Solutions | S5558-ND | 2 | CONN HDR 10POS 0.1 GOLD PCB R/A
MMBT2222A-7-F | Diodes Incorporated | MMBT2222A-FDICT-ND | 10 | TRANS NPN 40V 0.6A SMD SOT23-3
ERA-3AEB103V | Panasonic Electronic Components | P10KDBCT-ND | 24 | RES SMD 10K OHM 0.1% 1/10W 0603
ERA-3AEB104V | Panasonic Electronic Components | P100KDBCT-ND | 4 | RES SMD 100K OHM 0.1% 1/10W 0603
C0603C104K8RACTU | KEMET | 399-1095-1-ND | 8 | CAP CER 0.1UF 10V X7R 0603
GRM188R60G106ME47D | Murata Electronics | 490-3298-1-ND | 2 | CAP CER 10UF 4V X5R 0603
GRM188R61A105KA61D | Murata Electronics | 490-1543-1-ND | 1 | CAP CER 1UF 10V X5R 0603
MCP23S17T-E/SO | Microchip Technology | MCP23S17T-E/SOCT-ND | 1 | IC I/O EXPANDER SPI 16B 28SOIC
MCP3208-CI/SL | Microchip Technology | MCP3208-CI/SL-ND | 1 | IC ADC 12BIT SAR 16SOIC
LM324DR | Texas Instruments | 296-14597-1-ND | 1 | IC OPAMP GP 4 CIRCUIT 14SOIC
MCP4922T-E/SL | Microchip Technology | MCP4922T-E/SLCT-ND | 1 | IC DAC 12BIT V-OUT 14SOIC

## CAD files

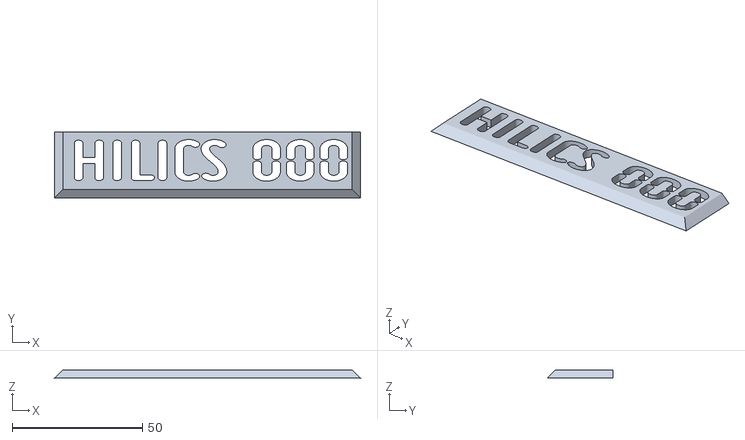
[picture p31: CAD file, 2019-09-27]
hardware/cad/Nameplates/stl_files/plate_000.stl
117.6 x 25.3 x 3.15

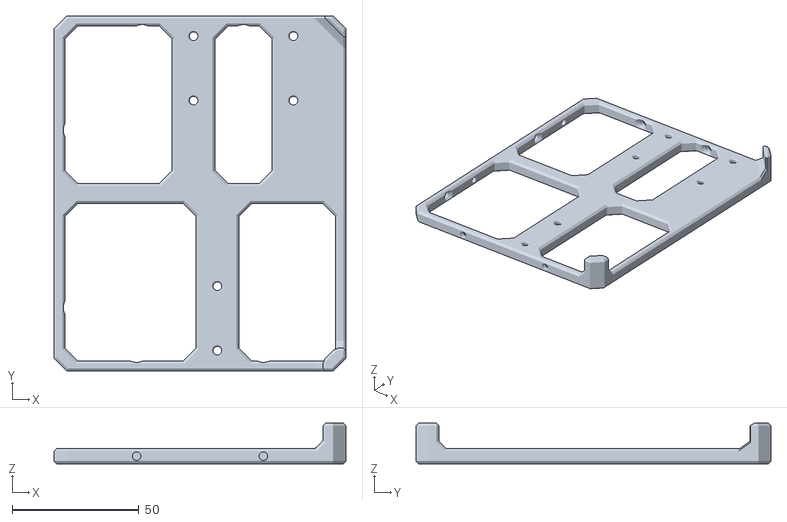
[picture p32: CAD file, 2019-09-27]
hardware/cad/stl_files/2x_HILICS_Pi_Frm.stl
115.0 x 140.0 x 16.0

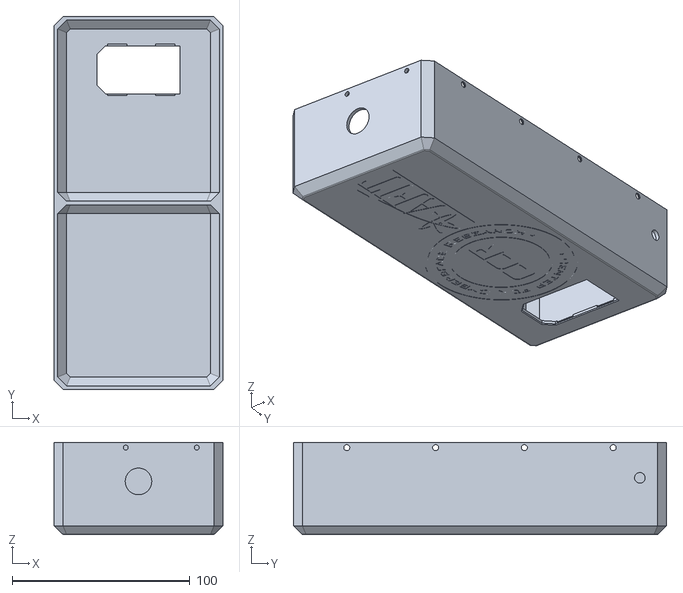
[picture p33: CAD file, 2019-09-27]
hardware/cad/stl_files/HILICS_Power_single_ext.stl
95.0 x 210.0 x 52.0

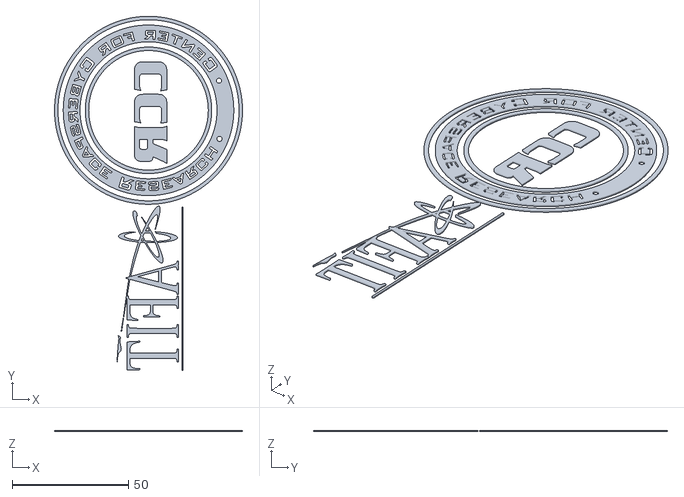
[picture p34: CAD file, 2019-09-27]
hardware/cad/stl_files/HILICS_Power_Color_2.stl
81.0 x 152.7 x 0.6

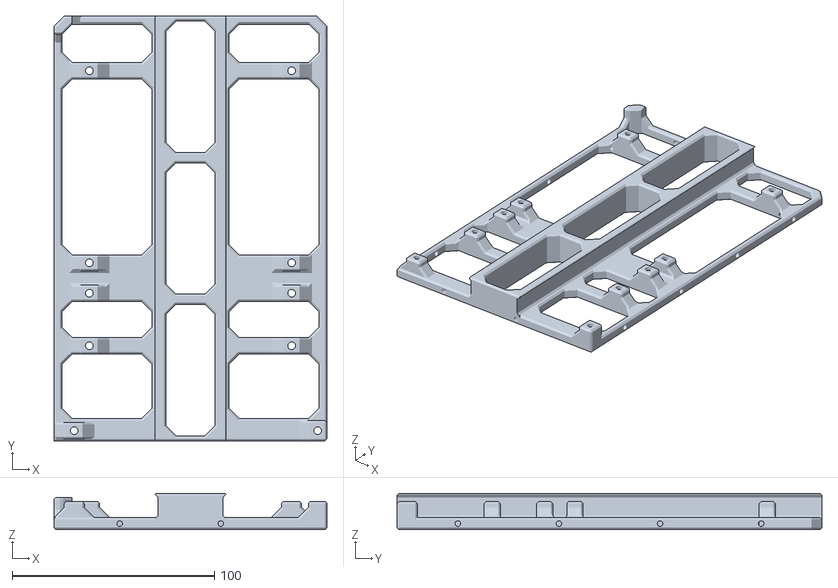
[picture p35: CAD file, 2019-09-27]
hardware/cad/stl_files/1x_HILICS_PLC_Frm.stl
135.0 x 210.0 x 18.0

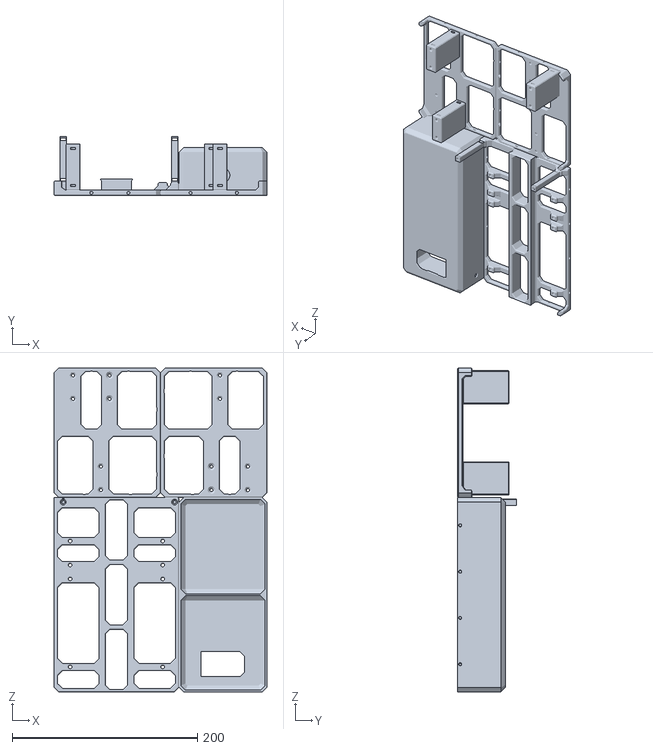
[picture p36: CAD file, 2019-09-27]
hardware/cad/stl_files/HILICS_AS.stl
230.0 x 64.0 x 350.0

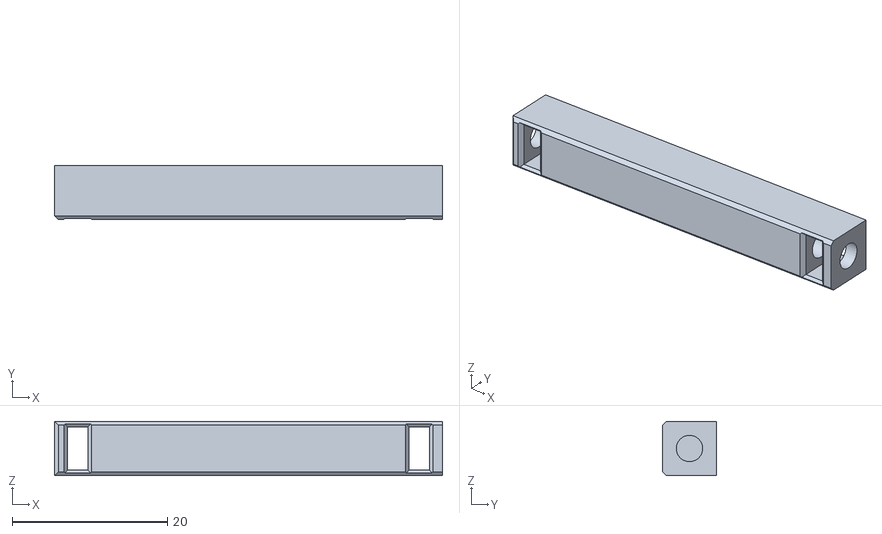
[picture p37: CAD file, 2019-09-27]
hardware/cad/stl_files/2x_PCB_Leg.stl
50.0 x 7.00 x 7.00

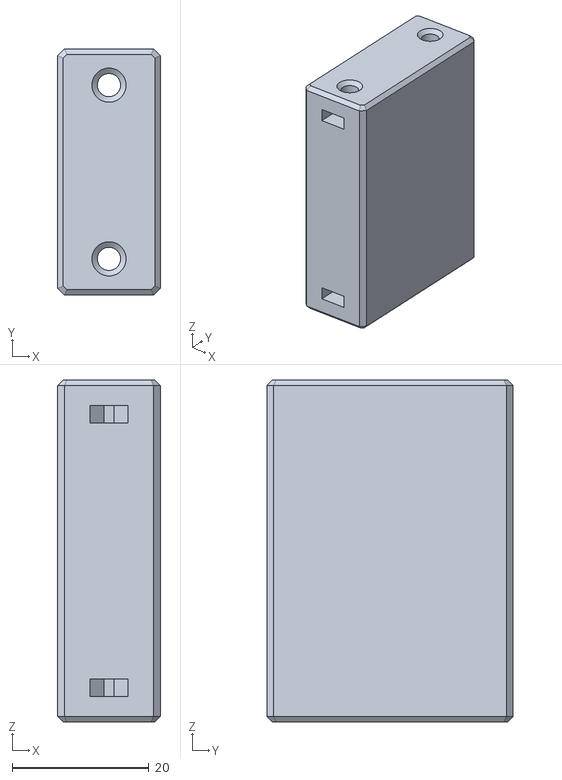
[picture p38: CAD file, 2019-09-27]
hardware/cad/stl_files/3x_HILICS_ExtBlck.stl
15.0 x 36.0 x 50.0

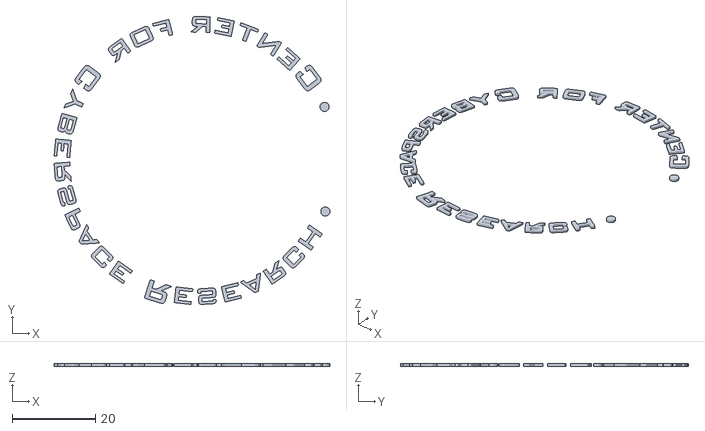
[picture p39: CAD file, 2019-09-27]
hardware/cad/stl_files/HILICS_Power_Color_1.stl
66.2 x 69.1 x 0.6

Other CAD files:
hardware/cad/Nameplates/stl_files/plate_007.stl
hardware/cad/Nameplates/stl_files/plate_004.stl
hardware/cad/Nameplates/stl_files/plate_005.stl
hardware/cad/Nameplates/stl_files/plate_006.stl
hardware/cad/Nameplates/stl_files/plate_002.stl
hardware/cad/Nameplates/stl_files/plate_003.stl
hardware/cad/stl_files/HILICS_Power_Color_3.stl
hardware/cad/Nameplates/stl_files/plate_009.stl
hardware/cad/Nameplates/stl_files/plate_001.stl
hardware/cad/Fusion360/HILICS_Power_single_ext.f3d
hardware/cad/Nameplates/stl_files/plate_008.stl
hardware/cad/Nameplates/stl_files/plate_010.stl

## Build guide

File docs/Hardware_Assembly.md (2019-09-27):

<div>
HILICSHILICS  
</div>
<br clear="all" />
<br>

This guide will walk you through the steps to assemble your HILICS training platform.

# Components

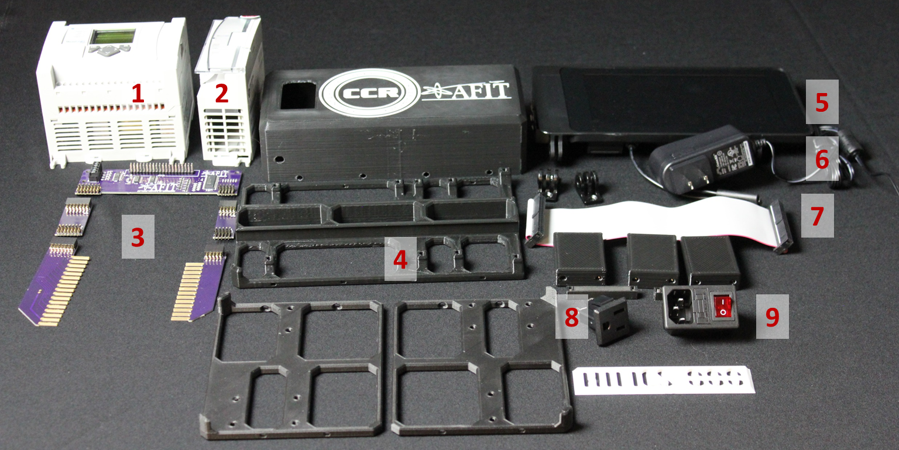
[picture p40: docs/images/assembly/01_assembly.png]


You will need the following components to assemble your HILICS kit. Further details and the BOM can be found [here.](./README.md)

1. 1763-L16BWA
1. 1762-OF4
1. [HILICS PCBs](../hardware/eagle/ML1100_Pi_Interface)
1. 3D Printed Parts:
	* [HILICS_Power_single_ext.stl](../hardware/cad/stl_files)
	* [1x_HILICS_PLC_Frm.stl](../hardware/cad/stl_files)
	* [2x_HILICS_Pi_Frm.stl](../hardware/cad/stl_files)
	* [3x_HILICS_ExtBlck.stl](../hardware/cad/stl_files)
	* [2x_PCB_Leg.stl](../hardware/cad/stl_files)
	* [HILICS nameplate](../hardware/cad/Nameplates/stl_files)
1. Raspberry Pi, touchscreen, case, SD card and hinges
1. Raspberry Pi power supply (5 VDC - 2.5 amp)
1. Raspberry Pi ribbon cable (40 pin)
1. Panel-mount power socket with fuse and switch
1. 110 VAC panel mount outlet

Additional components:

1. M3x8mm countersunk bolts.
1. M3x12mm countersunk bolts.
1. M3x10mm pan head bolts (longer will also work).
1. M3 nuts.
1. M4x8mm pan head bolts (longer will also work).
1. 22 AWG stranded wire.
1. 18 AWG stranded wire.

# Part 1 - Raspberry Pi half

* Assemble the Raspberry Pi, touchscreen and touchscreen case using the directions that came with them. Leave the screen protector in place to protect it during the rest of the assembly.

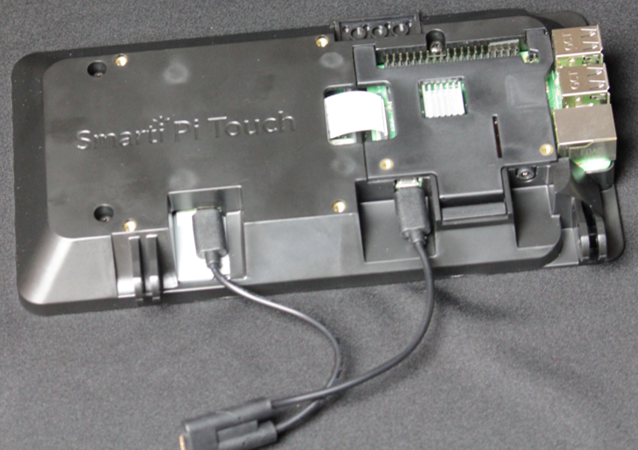
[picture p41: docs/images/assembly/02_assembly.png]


* Connect the two Raspberry Pi frame halves (2x_HILICS_Pi_Frm.stl) together using four M3x8mm countersunk bolts. Note the orientation of the vertical tabs.

	**WARNING: Do not over-tighten the bolts or you will strip the plastic.**

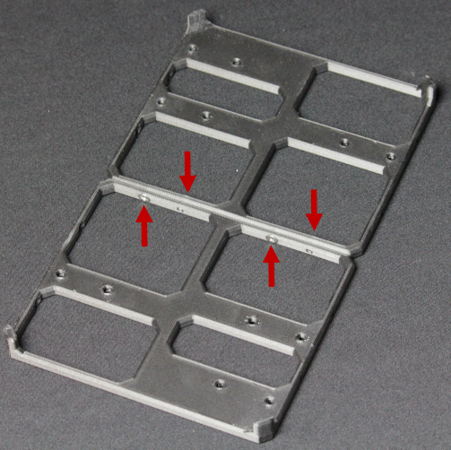
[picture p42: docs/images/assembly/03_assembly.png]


* Place four M3 nuts in each of the two hinge mounts (3x_HILICS_ExtBlck.stl). 
* Place two M3 nuts in the support block (3x_HILICS_ExtBlck.stl).
* Use four M3x12mm countersunk bolts to attach the two hinge mounts to the outside positions on one side of the frame.
* Use two M3x12mm countersunk bolts to attach the support block to the middle position on the other side of the frame. This block is simply to support the Raspberry Pi Touchscreen when the kit is closed. The top two holes are not used.
* Attach the case hinges to the hinge mounts (3x_HILICS_ExtBlck.stl).

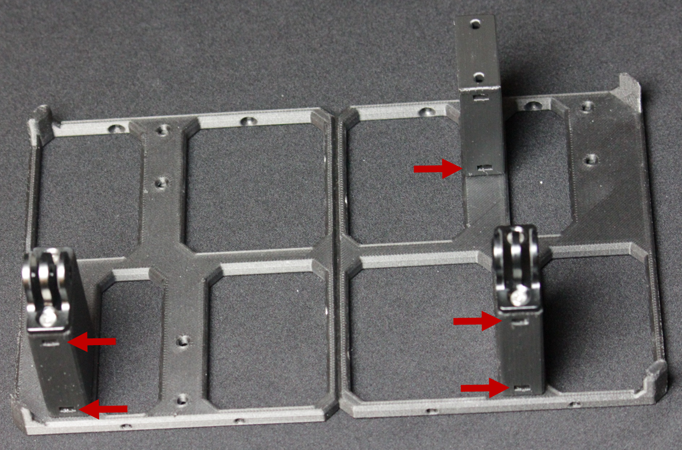
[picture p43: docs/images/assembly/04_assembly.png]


* Attach the Raspberry Pi to the hinges. 

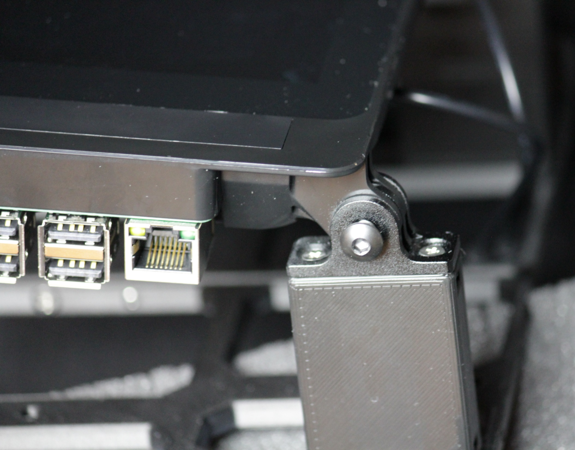
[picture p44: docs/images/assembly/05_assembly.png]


* Set this half of the kit to the side for later.

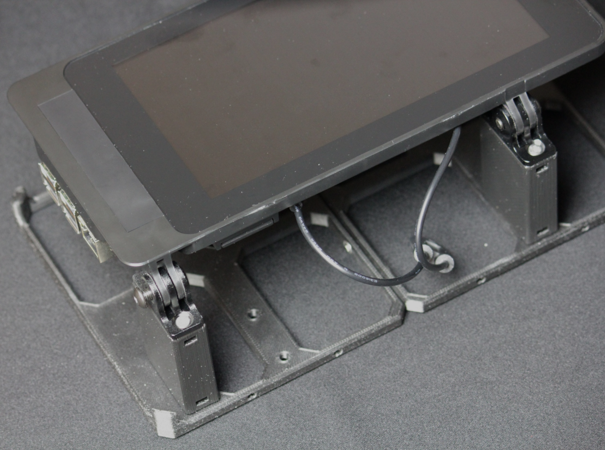
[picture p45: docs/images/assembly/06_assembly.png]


# Part 2 - PLC half

* Attach the ML1100 to the DIN rail on the PLC frame (1x_HILICS_PLC_Frm.stl) and position the PLC so that the mounting points line up as shown.
* Place two M3 nuts in each PCB standoff and attach them to the base using M3x12mm countersunk bolts.

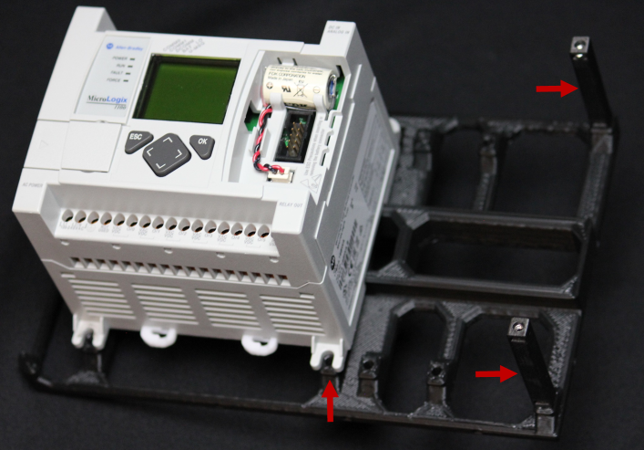
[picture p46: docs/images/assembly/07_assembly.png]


* Attach the expansion module to the DIN rail. Plug the ribbon cable in to the MicroLogix 1100 and push the two together. 

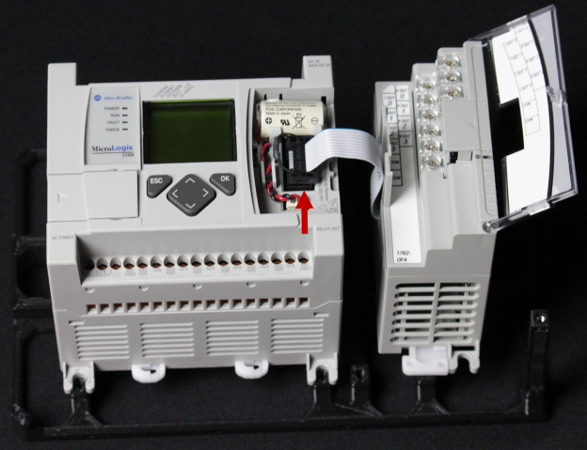
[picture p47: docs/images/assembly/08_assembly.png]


* Secure the PLC and Expansion module in place using one M4x8mm screw in each. You can use more than one screw each if you like to be paranoid.

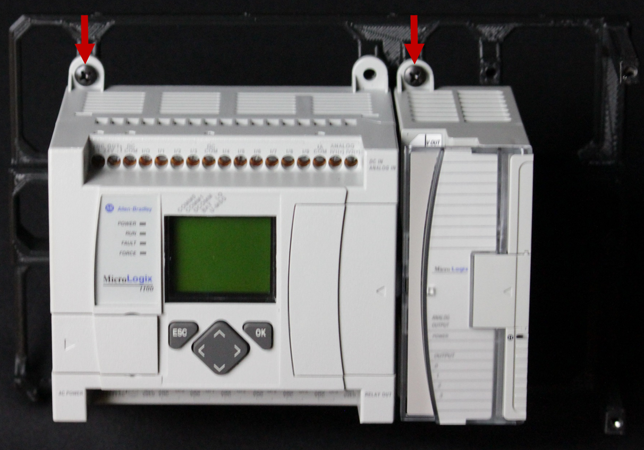
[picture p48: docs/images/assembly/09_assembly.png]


* Slide the comb-shaped PCBs into the sides of the ML1100 and tighten ALL of the screw terminals on the PLC.
**NOTE: The three 100-240 VAC terminals should be empty at this point.**

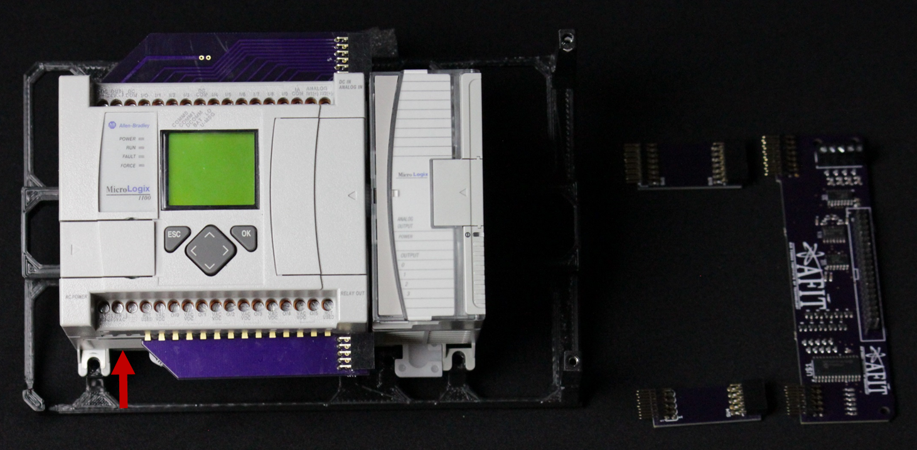
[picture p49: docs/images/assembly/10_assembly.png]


* Attach the two PCB extenders to the comb-shaped PCBs.
* Attach the main board to the PCB extenders. 
* Secure the main board to the PCB legs using two M3x10mm pan head bolts.

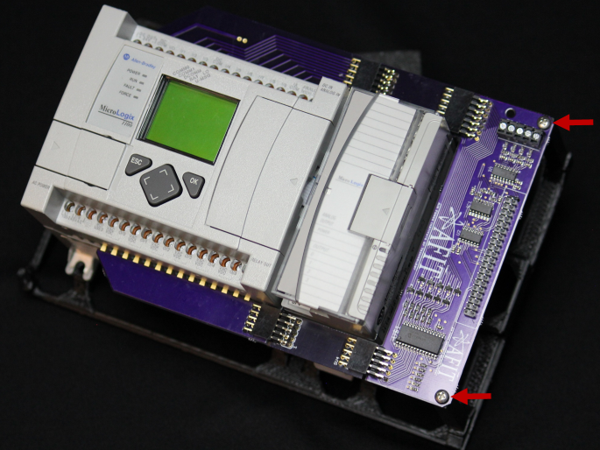
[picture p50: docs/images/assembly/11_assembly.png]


* Wire the analog output module's **VOUT** terminals to the screw terminals on the main board as shown. We recommend using 22 AWG stranded wire. 
* **Pay attention to the labels on the PCB and expansion module.**
* **The IOUT (lower level) terminals on the expansion module should not be connected.**

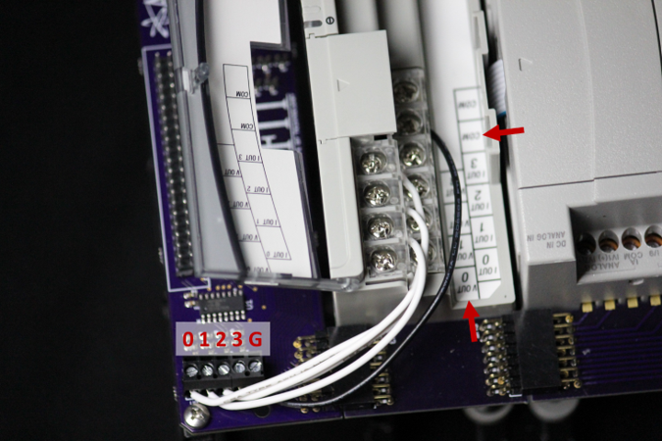
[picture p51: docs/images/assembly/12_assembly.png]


* Attach the two power connectors to the power box (HILICS_Power_single_ext.stl).
* Attach the power box to the MicroLogix frame using 4 M3x8mm countersunk bolts.

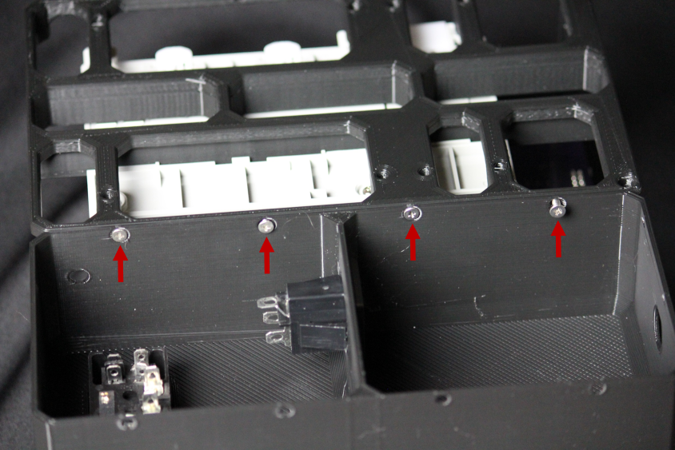
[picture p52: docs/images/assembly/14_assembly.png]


**WARNING: do not work on the system while power is connected. It's not my fault if you electrocute yourself.**

* Wire the power connectors using 18 AWG stranded wire and crimp-on spade connectors. Make sure the spade connectors are crimped correctly.
* Plug the Raspberry Pi power supply into the 110 VAC outlet inside the power box. 

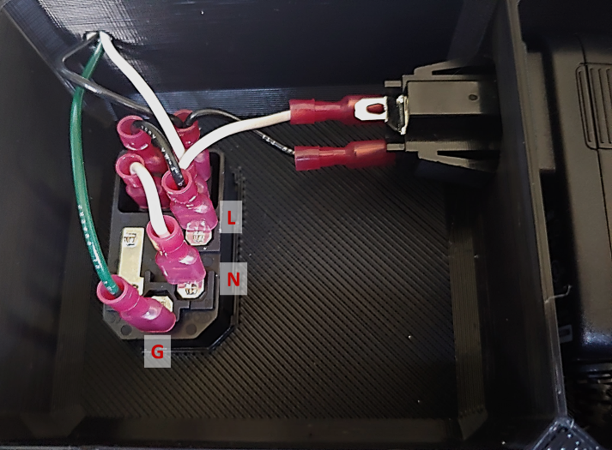
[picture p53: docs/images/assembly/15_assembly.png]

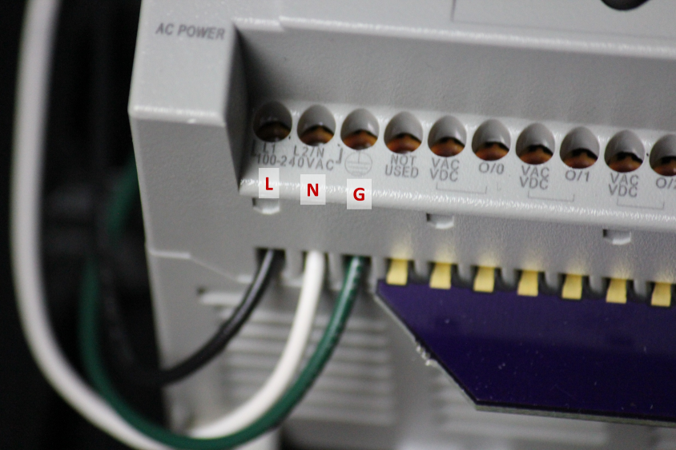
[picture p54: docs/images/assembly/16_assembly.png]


# Part 3 - Assemble the halves

* Connect the two halves together using four M3x8mm countersunk bolts.
 
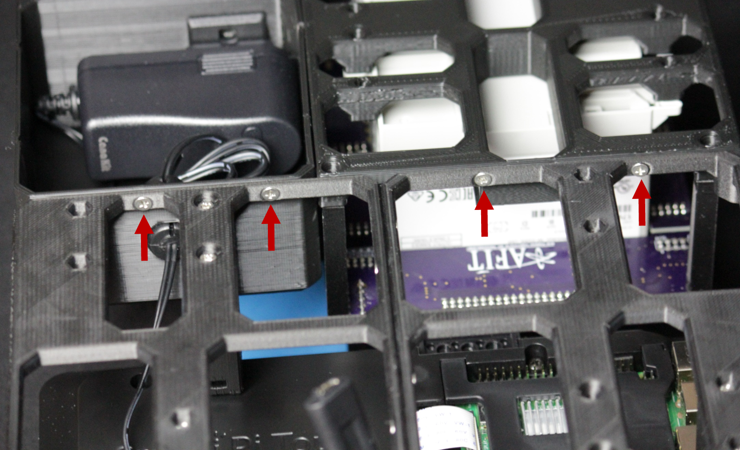
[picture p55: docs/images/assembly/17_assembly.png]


* Feed the end of the Raspberry Pi power cable through the hole in the power box.

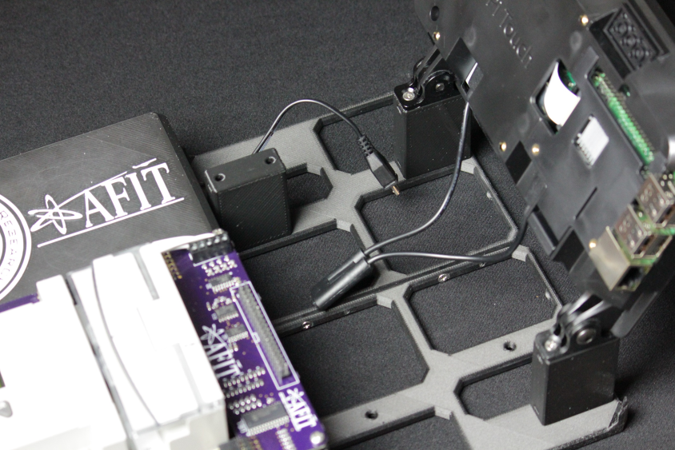
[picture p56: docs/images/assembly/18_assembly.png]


* Plug the Raspberry Pi power cable into the Raspberry Pi USB splitter.
* Connect the Raspberry Pi to the main PCB using the 40-pin ribbon cable.
<br>**Note: The arrows denote the orientation of the ribbon cable connector tabs.**

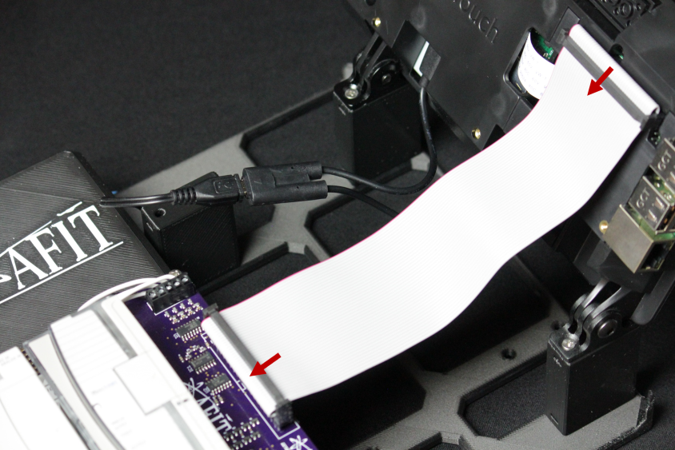
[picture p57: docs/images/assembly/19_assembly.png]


* Your kit is assembled! All that's needed now is to put it in the Pelican 1450 case.

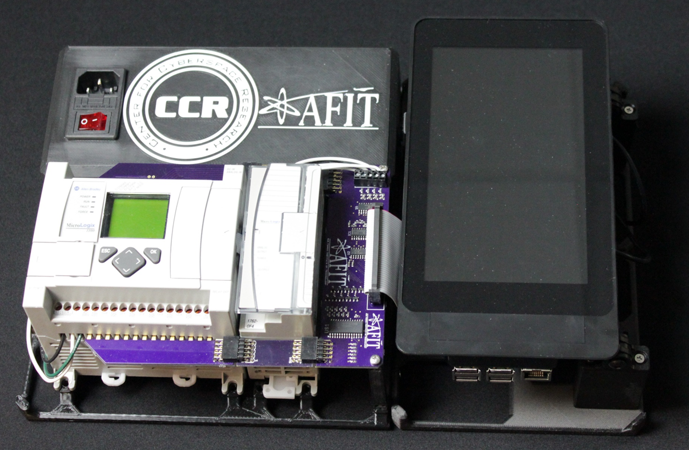
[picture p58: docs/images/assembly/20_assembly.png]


# Part 4 - Pelican 1450

* Remove the "Pick N'Pluck" foam from the Pelican 1450 case. 
* Separate the outer ring of foam from the inside. Throw the inside foam away (or save it for packing material).

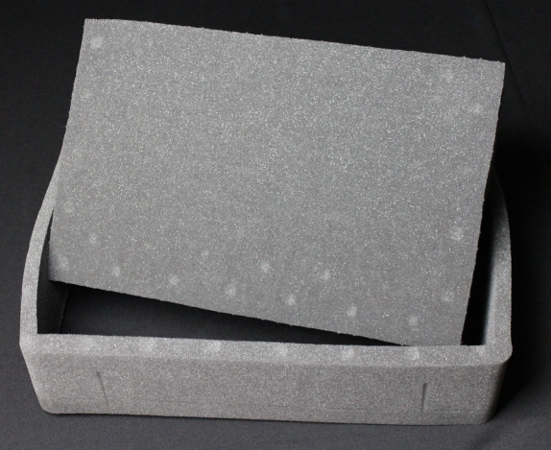
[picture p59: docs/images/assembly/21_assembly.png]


* Place the ring of foam in the case. You should now have the bottom foam, top foam and the outer ring.

	Note: Some of the Pelican cases we received had a narrower ring than others, causing the kit to be loose. If this happens, leave one row of Pick N'Pluck foam attached to the outer ring to get a tighter fit.

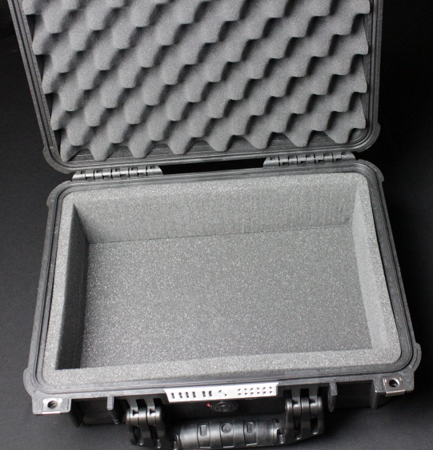
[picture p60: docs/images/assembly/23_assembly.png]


* Remove the plaque from the front of the Pelican case. Replace it with the HILICS nameplate.

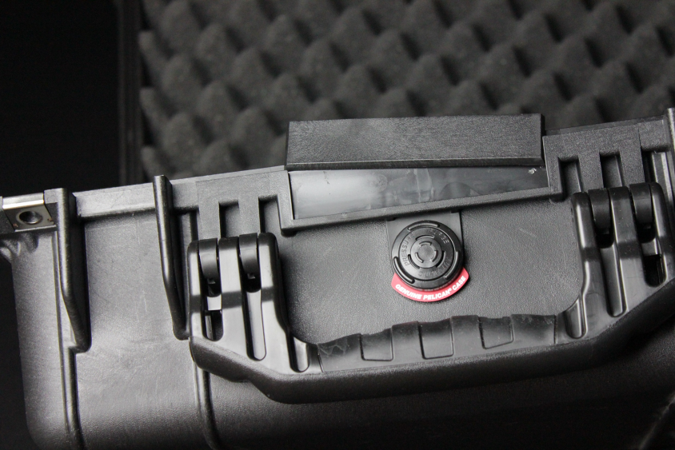
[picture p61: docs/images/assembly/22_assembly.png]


* Slide the assembled HILICS kit into the Pelican case.

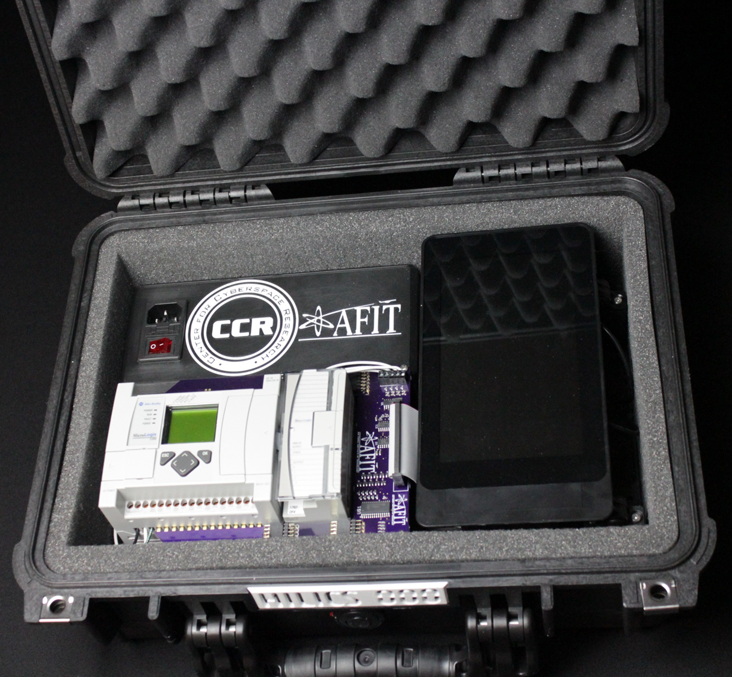
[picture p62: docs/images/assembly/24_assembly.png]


Congratulations, your ready to move on to the next step!

<br><br><br>

Previous: [Raspberry Pi setup](./RPi_Setup.md)

Return: [Build a kit](./README.md)

Next: [Install Rockwell Tools](./Rockwell_Tools.md)

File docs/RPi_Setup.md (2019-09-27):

<div>
HILICSHILICS  
</div>

<br clear="all" />
<br>

# Install Raspbian

* Assemble your Raspberry Pi and touchscreen.

* Download the latest [Raspbian distro with desktop](https://www.raspberrypi.org/downloads/raspbian/) and follow the [installation guide](https://www.raspberrypi.org/documentation/installation/installing-images/README.md) for a default setup. NOTE: HILICS has only been tested using Raspbian Buster, but should work on other versions as well. 

* After Raspbian is installed, follow the instructions to configure keyboard and time settings, install updates, and reboot.

* Once finished, you will need to connect a mouse and keyboard or [enable SSH](https://www.raspberrypi.org/documentation/remote-access/ssh/) to continue.

# Download python files

* Run the following commands in a terminal to install HILICS.

```
cd /tmp/
git clone https://github.com/sdunlap-afit/hilics.git

chmod +x ./hilics/src/scripts/install.sh
./hilics/src/scripts/install.sh

rm -r /tmp/hilics
```

<br><br><br>

Return: [Build a kit](./README.md)

Next: [Hardware assembly](./Hardware_Assembly.md)

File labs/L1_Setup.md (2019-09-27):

<div>
HILICSHILICS  
</div>
<br clear="all" />
<br>

# Lab 1 - Setup and Familiarization

# Intro
In this lab you will setup your HILICS training platform. This process includes understanding how to connect to the kit, program the PLC, and test the hardware using the [IO_Test.RSS](./LadderLogic_Examples/) example project.

# HILICS Contents

**WARNING! Do not remove the system from the Pelican case while power is connected.**

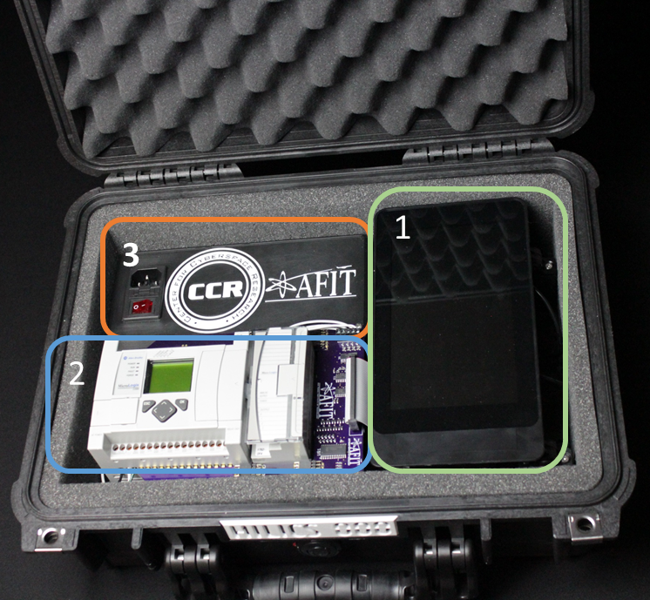
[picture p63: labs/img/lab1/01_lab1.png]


1. Raspberry PI touchscreen - process simulator.
2. MicroLogix 1100 - Programmable Logic Controller.
3. Power connector and switch.

# Procedure

1. Open your HILICS case and plug in the power.

2. Use an Ethernet cable to connect the **PLC** to your **computer.**

	**NOTE: do not connect anything to the Raspberry Pi.**

3. If necessary, follow the PLC Setup instructions [here.](../docs/README.md#PLC-setup)

4. At this point you should be able to ping the PLC. 

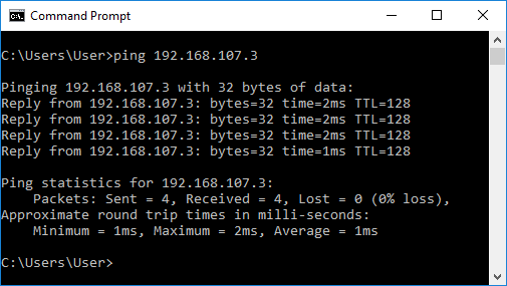
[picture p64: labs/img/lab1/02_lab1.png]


5. Start RSLogix Micro and open Desktop\Projects\IO_Test.

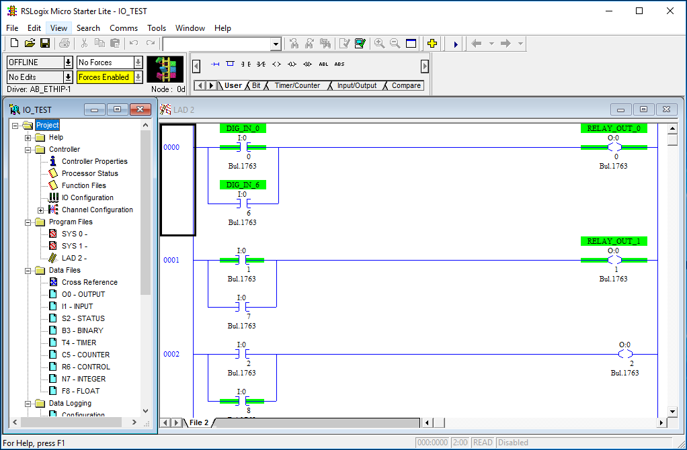
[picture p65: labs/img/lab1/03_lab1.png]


6. Open the Comms >> System Comms menu.
7. Select the IP of your PLC.
8. Download the program, clicking through the numerous, pointless and annoying pop ups.
	
	Note: In this program, “download” means write the program to the PLC. This naming scheme is backwards and annoying.

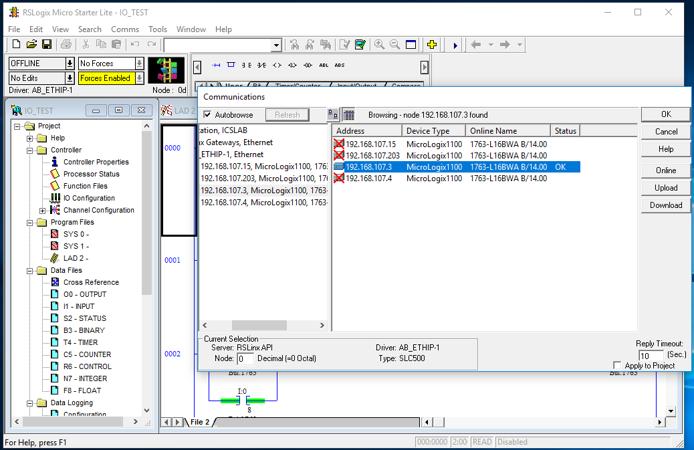
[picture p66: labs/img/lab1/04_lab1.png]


9. Run the **IO_Test** application on the **Raspberry Pi**. This application is used to test the inputs and outputs of the PLC. The IO_Test ladder logic program copies the state of the Digital Inputs to the Relay Outputs. It also copies the voltage from the Analog Inputs to the Analog Outputs. Use this to verify that all IO is working.

	**Note:** the labels in this application match the addressing scheme used by RSLogix Micro. Pay close attention to the difference between ‘/’ and ‘.’ for inputs. 
	
	I:0.4 is analog input 1 (IV1). 
	
	I:0/4 is digital input 4.

10. While in **Online** mode with the PLC, compare the ladder logic interface to the Touchscreen to gain an understanding of the logic and hardware. Additionally you can check the status of the digital inputs and outputs on the PLC under the IO_STATUS option.

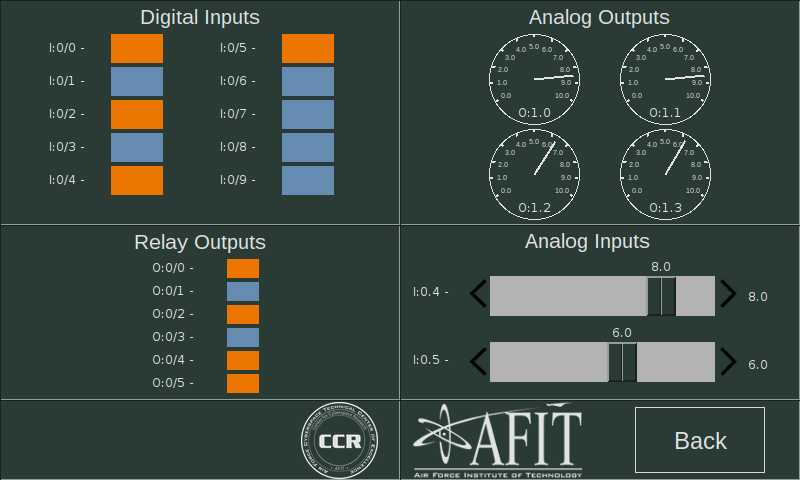
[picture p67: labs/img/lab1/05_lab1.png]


# IO Test Modification

1. First take a look at [this tutorial](https://www.allaboutcircuits.com/textbook/digital/chpt-6/programmable-logic-controllers-plc/) to learn how ladder logic works with PLCs.  

1. Take the IO_Test.RSS program and make some modifications. The new IO_Test program should have the following features (It is recommended to copy the existing program before making modifications)

1. If analog input I:0.4 is above 5.0V, then digital output O:0/5 should be high.

1. If digital inputs I:0/7, I:0/8 and I:0/9 are all high, then analog output O:1.3 should be set to 7.0V.

1. The PLC sees the analog inputs and outputs as integers not as floating point numbers. See the existing ladder logic for an example of how to interpret the values.

	**NOTE:** It is best practice to only read inputs or write outputs in one place. Inputs can change any time causing conflicting values and writing to the same output in multiple places can cause the output to misbehave.

<br><br>
[Return](./README.md)

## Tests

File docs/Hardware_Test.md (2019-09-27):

<div>
HILICSHILICS  
</div>
<br clear="all" />
<br>

# Hardware test

This guide will walk you through the test to make sure your HILICS training platform is functioning properly. 

## 1. Download IO_Test.RSS to PLC

Follow the instructions from [the previous step](./RSLogix_Net_Config.md) to load [IO_Test.RSS](../labs/LadderLogic_Examples/) and download it to the PLC.

## 2. Open the IO_Test app on the Raspberry Pi

This application is used to test the inputs and outputs of the PLC and the HILICS PCB. The IO_Test.RSS ladder logic copies the state of the Digital Inputs to the Relay Outputs. It also copies the value from the Analog Inputs to the Analog Outputs.

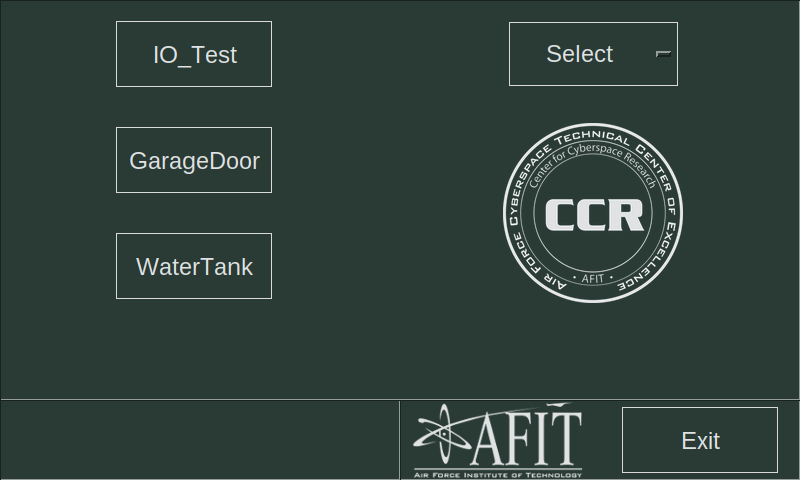
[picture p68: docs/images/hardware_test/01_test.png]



## 3. Test the digital inputs and outputs.

Use the touchscreen to activate all ten of the Digital Inputs. The PLC's ladder logic should activate all of the Relay Outputs.

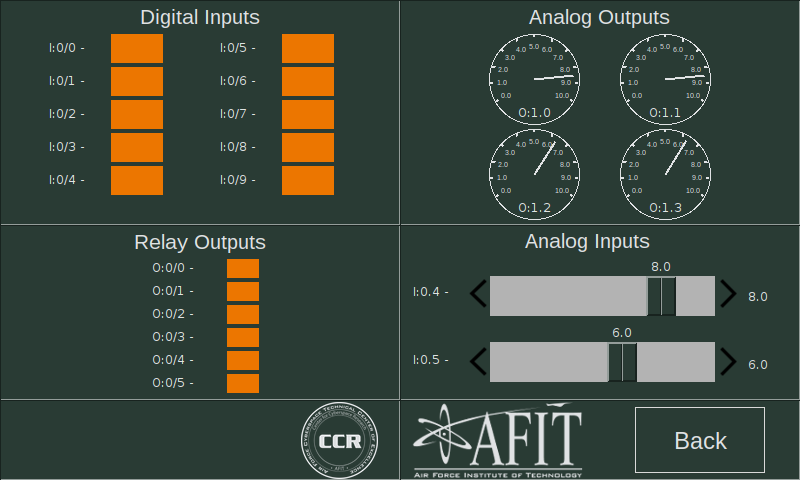
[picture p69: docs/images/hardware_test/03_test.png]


Look at the display on the front of the PLC. If everything is working, all of the blocks next to "I" and "O" should be filled in, indicating that all inputs and outputs are activated.

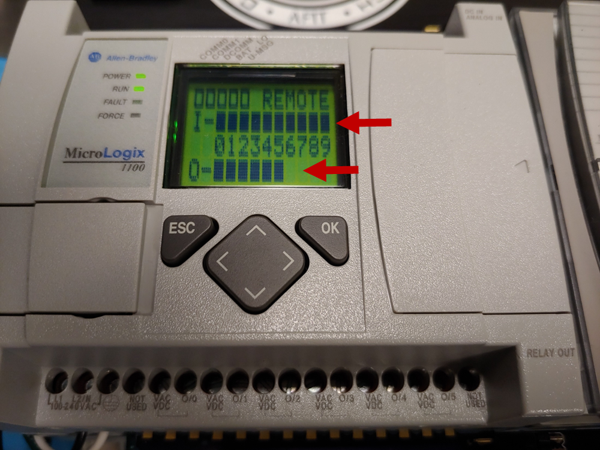
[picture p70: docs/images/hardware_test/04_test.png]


## 4. Test the analog inputs and outputs.

Use the touchscreen to slide the Analog Inputs slider up and down. The PLC's ladder logic should copy the value of Analog Input 1 (I:0/4) to both Analog Outputs 0 and 1 (O:1.0 and O:1.1). It should also copy the value of Analog Input 2 (I:0/5) to both Analog Outputs 2 and 3 (O:1.2 and O:1.3).

If any of the values are incorrect, use RSLogix Micro to check the value of the Analog Inputs.

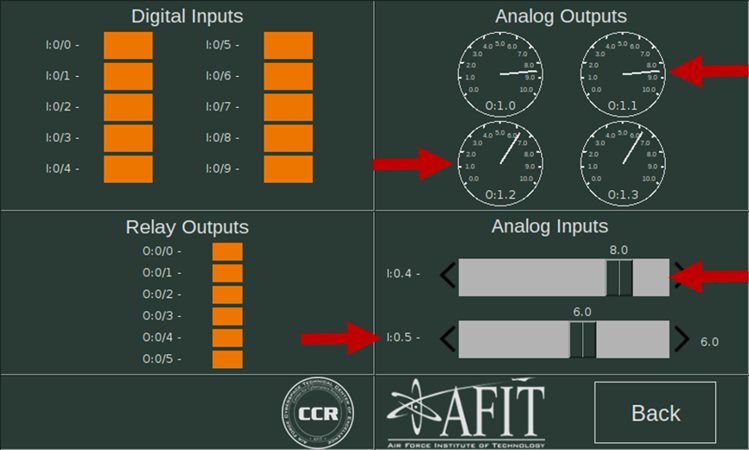
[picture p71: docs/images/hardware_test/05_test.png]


# Troubleshooting

If any of the inputs or outputs do not pass the tests, it is most likely an issue with the HILICS PCB (especially if you hand-soldered them). Follow these steps to correct the issue.

1. Always troubleshoot PLC inputs before PLC outputs.
1. Make sure the Raspberry Pi ribbon cable is plugged in securely.
1. Make sure the PLC screw terminals are all tightened down.
1. Make sure all PCB components are soldered correctly and check for cold solder joints and short circuits.
1. Make sure resistors for the analog components are the correct values (10K for Analog Outputs and 100K for Analog Inputs).

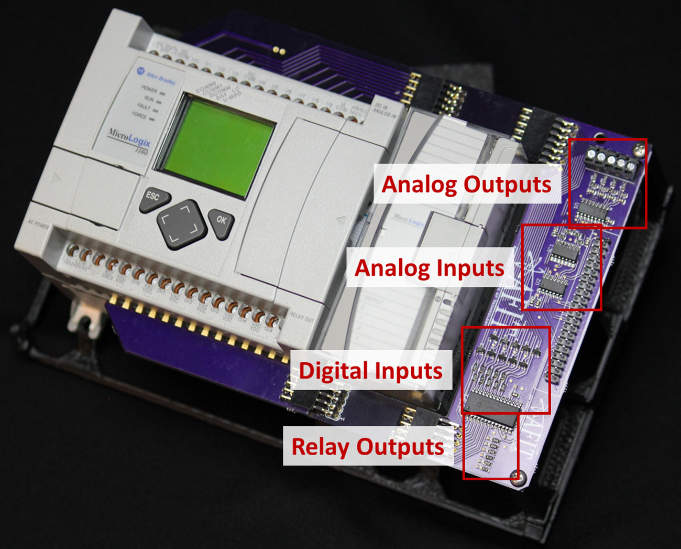
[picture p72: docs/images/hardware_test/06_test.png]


<br><br><br>

Previous: [Configure RSLogix project](./RSLogix_Net_Config.md)

Return: [Build a kit](./README.md)

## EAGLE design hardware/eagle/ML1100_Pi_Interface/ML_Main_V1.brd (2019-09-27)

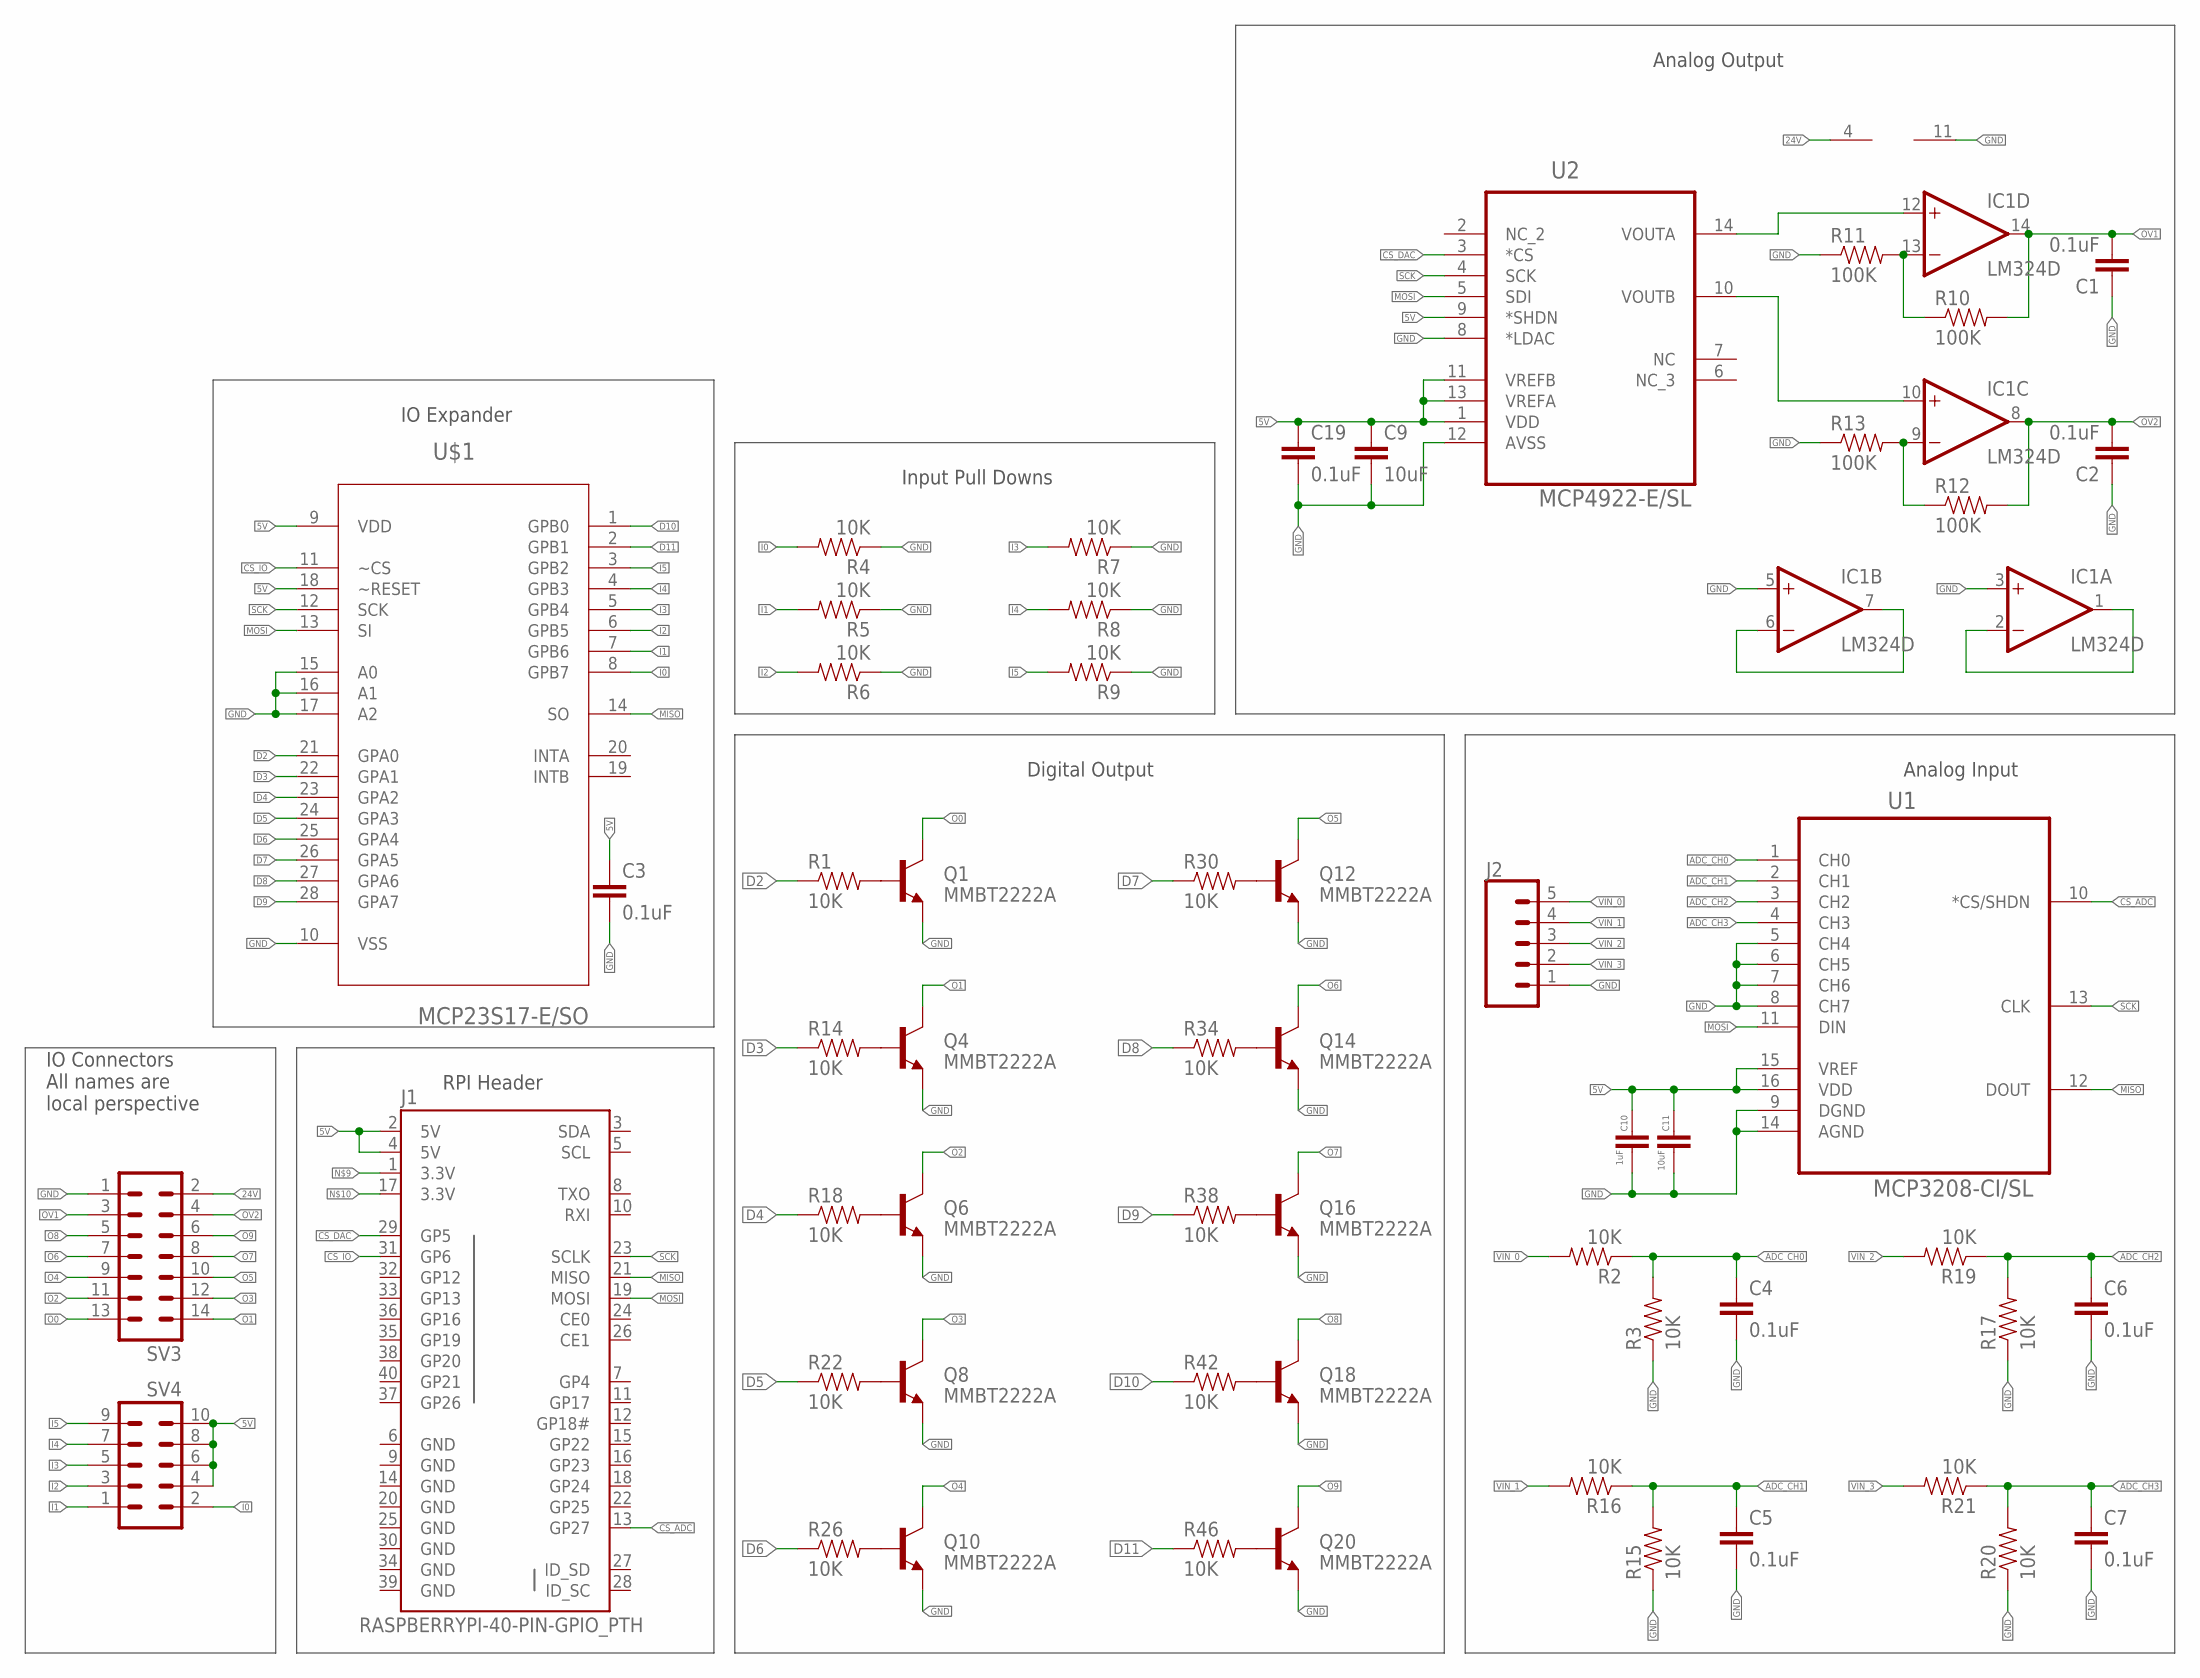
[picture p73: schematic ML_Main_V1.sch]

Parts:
C1, C2, C3, C4, C5, C6, C7, C19: 0.1uF; 0603-CAP
C9, C11: 10uF; 0603-CAP
C10: 1uF; 0603-CAP
IC1: LM324D; SO14
J1: RASPBERRYPI-40-PIN-GPIO_PTH; 2X20_SHROUDED
J2: CONN_05SCREW; SCREWTERMINAL-3.5MM-5
Q1, Q4, Q6, Q8, Q10, Q12, Q14, Q16, Q18, Q20: MMBT2222A; SOT23-3
R1, R2, R3, R4, R5, R6, R7, R8, R9, R14, R15, R16, R17, R18, R19, R20, R21, R22, R26, R30, R34, R38, R42, R46: 10K; 0603-RES
R10, R11, R12, R13: 100K; 0603-RES
SV3: MA07-2W
SV4: MA05-2
U1: MCP3208-CI/SL; SOIC127P600X175-16N
U2: MCP4922-E/SL; SOIC127P600X175-14N
U$1: MCP23S17-E/SO; SOIC127P030X265-28N

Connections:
5V: C3.1, C9.1, C10.1, C11.1, C19.1, J1.2 (5V), J1.4 (5V), SV4.4, SV4.6, SV4.8, SV4.10, U1.15 (VREF), U1.16 (VDD), U2.1 (VDD), U2.9 (*SHDN), U2.11 (VREFB), U2.13 (VREFA), U$1.9 (VDD), U$1.18 (~RESET)
24V: IC1.4 (V+), SV3.2
ADC_CH0: C4.1, R2.1, R3.2, U1.1 (CH0)
ADC_CH1: C5.1, R15.2, R16.1, U1.2 (CH1)
ADC_CH2: C6.1, R17.2, R19.1, U1.3 (CH2)
ADC_CH3: C7.1, R20.2, R21.1, U1.4 (CH3)
CS_ADC: J1.13 (GP27), U1.10 (*CS/SHDN)
CS_DAC: J1.29 (GP5), U2.3 (*CS)
CS_IO: J1.31 (GP6), U$1.11 (~CS)
D2: R1.1, U$1.21 (GPA0)
D3: R14.1, U$1.22 (GPA1)
D4: R18.1, U$1.23 (GPA2)
D5: R22.1, U$1.24 (GPA3)
D6: R26.1, U$1.25 (GPA4)
D7: R30.1, U$1.26 (GPA5)
D8: R34.1, U$1.27 (GPA6)
D9: R38.1, U$1.28 (GPA7)
D10: R42.1, U$1.1 (GPB0)
D11: R46.1, U$1.2 (GPB1)
GND: C1.1, C2.1, C3.2, C4.2, C5.2, C6.2, C7.2, C9.2, C10.2, C11.2, C19.2, IC1.3 (+IN), IC1.5 (+IN), IC1.11 (V-), J1.6 (GND), J1.9 (GND), J1.14 (GND), J1.20 (GND), J1.25 (GND), J1.30 (GND), J1.34 (GND), J1.39 (GND), J2.1, Q1.2 (E), Q4.2 (E), Q6.2 (E), Q8.2 (E), Q10.2 (E), Q12.2 (E), Q14.2 (E), Q16.2 (E), Q18.2 (E), Q20.2 (E), R3.1, R4.1, R5.1, R6.1, R7.1, R8.1, R9.1, R11.1, R13.1, R15.1, R17.1, R20.1, SV3.1, U1.5 (CH4), U1.6 (CH5), U1.7 (CH6), U1.8 (CH7), U1.9 (DGND), U1.14 (AGND), U2.8 (*LDAC), U2.12 (AVSS), U$1.10 (VSS), U$1.15 (A0), U$1.16 (A1), U$1.17 (A2)
I0: R4.2, SV4.2, U$1.8 (GPB7)
I1: R5.2, SV4.1, U$1.7 (GPB6)
I2: R6.2, SV4.3, U$1.6 (GPB5)
I3: R7.2, SV4.5, U$1.5 (GPB4)
I4: R8.2, SV4.7, U$1.4 (GPB3)
I5: R9.2, SV4.9, U$1.3 (GPB2)
MISO: J1.21 (MISO), U1.12 (DOUT), U$1.14 (SO)
MOSI: J1.19 (MOSI), U1.11 (DIN), U2.5 (SDI), U$1.13 (SI)
unnamed: IC1.13 (-IN), R10.1, R11.2
unnamed: Q1.1 (B), R1.2
unnamed: IC1.10 (+IN), U2.10 (VOUTB)
unnamed: IC1.12 (+IN), U2.14 (VOUTA)
unnamed: IC1.9 (-IN), R12.1, R13.2
unnamed: IC1.1 (OUT), IC1.2 (-IN)
unnamed: IC1.6 (-IN), IC1.7 (OUT)
unnamed: Q4.1 (B), R14.2
unnamed: Q6.1 (B), R18.2
unnamed: Q8.1 (B), R22.2
unnamed: Q10.1 (B), R26.2
unnamed: Q12.1 (B), R30.2
unnamed: Q14.1 (B), R34.2
unnamed: Q16.1 (B), R38.2
unnamed: Q18.1 (B), R42.2
unnamed: Q20.1 (B), R46.2
O0: Q1.3 (C), SV3.13
O1: Q4.3 (C), SV3.14
O2: Q6.3 (C), SV3.11
O3: Q8.3 (C), SV3.12
O4: Q10.3 (C), SV3.9
O5: Q12.3 (C), SV3.10
O6: Q14.3 (C), SV3.7
O7: Q16.3 (C), SV3.8
O8: Q18.3 (C), SV3.5
O9: Q20.3 (C), SV3.6
OV1: C1.2, IC1.14 (OUT), R10.2, SV3.3
OV2: C2.2, IC1.8 (OUT), R12.2, SV3.4
SCK: J1.23 (SCLK), U1.13 (CLK), U2.4 (SCK), U$1.12 (SCK)
VIN_0: J2.5, R2.2
VIN_1: J2.4, R16.2
VIN_2: J2.3, R19.2
VIN_3: J2.2, R21.2

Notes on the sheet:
IO Connectors All names are local perspective
Digital Output
Input Pull Downs
Analog Output
RPI Header
IO Expander
Analog Input

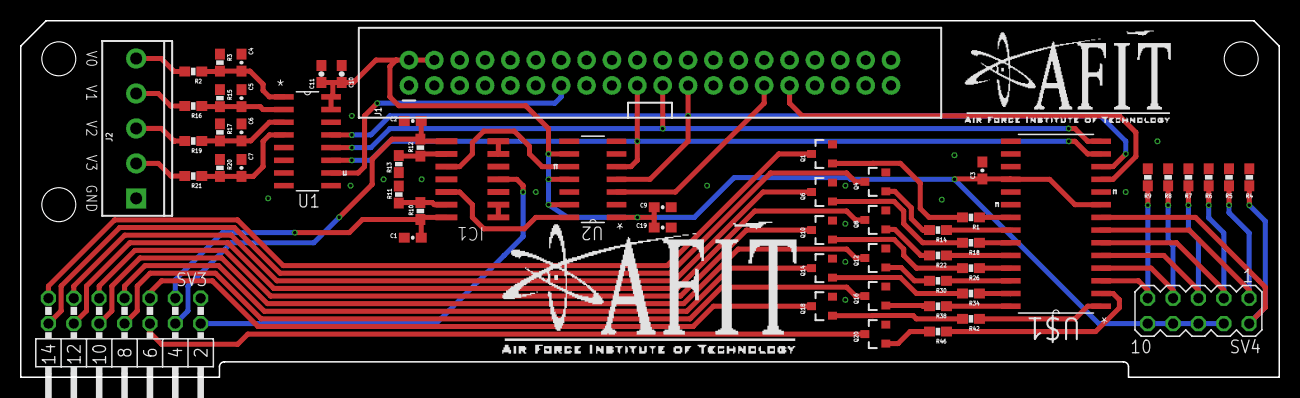
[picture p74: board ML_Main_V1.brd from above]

Board: 2 copper layers, 126.0 x 35.7 mm, 57 parts (0 on the bottom side), 61 nets.

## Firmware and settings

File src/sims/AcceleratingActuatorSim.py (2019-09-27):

#!/usr/bin/env python
#
# IP: HILICS
#
# Licensed under the Apache License, Version 2.0 (the "License");
# you may not use this file except in compliance with the License.
# You may obtain a copy of the License at
# 
#     http://www.apache.org/licenses/LICENSE-2.0
# 
# Unless required by applicable law or agreed to in writing, software
# distributed under the License is distributed on an "AS IS" BASIS,
# WITHOUT WARRANTIES OR CONDITIONS OF ANY KIND, either express or implied.
# See the License for the specific language governing permissions and
# limitations under the License.


import math


##### Description
#
# This class provides a simulation for an actuator that takes into account
# Position, Velocity and Acceleration.
#
# These values can represent any actuator
#
# Pump Example:
# 	RPM 	- current "position"
#	RPM/s	- current "velocity"
#	RPM/s/s	- current "acceleration"
# 
# This level of simulation is necessary for processes that use PID control.
# 
# Without this realism, the process is too "ideal" and the PID
# control works perfectly without any tuning.
#

class AcceleratingActuatorSim:



	# All values should be positive
	def __init__(self, max_p, max_v, max_a, allow_reverse=False):
		
		
		# Current position
		self.position = 0.0
		self.velocity = 0.0
		self.acceleration = 0.0
		
		
		# maximum position
		self.max_p = abs(max_p)

		# DeltaP/s
		self.max_v = abs(max_v)

		# DeltaV/s
		self.max_a = abs(max_a)
		
		self.allow_reverse = allow_reverse
		self.reverse = False
		
		# Percent of max flow rate
		# setpoint should always be positive
		self.setpoint = 100.0
		
		self.enabled = False
	
		self.alarm = False
		self.alarm_time = 0.0
		self.alarm_timeout = 2.0
		
		# Should be positive
		self.reverse_limit = 1.0
	
	
	
	def avg(self, nums):
		return sum(nums)/len(nums)
	
	
	
	def alarm_reset(self, time_dif):
		if self.alarm:
			self.alarm_time += time_dif
			
			if self.alarm_time > self.alarm_timeout:
				self.alarm = False
				self.alarm_time = 0.0
	
	
	
	def check_rev_alarm(self, target_p):
		if self.reverse_limit < 0.0:
			self.reverse_limit = 0.0 - self.reverse_limit
		
		if target_p > self.reverse_limit and self.position < -self.reverse_limit:
			self.alarm = True
			
		if target_p < -self.reverse_limit and self.position > self.reverse_limit:
			self.alarm = True
	
	
	
	
	def clamp(self, n, minn, maxn):
		return max(min(maxn, n), minn)
	
	
	
	
	def update(self, time_dif):
		
		self.alarm_reset(time_dif)
		
		if self.setpoint < 0.0:
			self.setpoint = 0.0 - self.setpoint
		
		
		
		# Target position based on setpoint
		target_p = self.setpoint * self.max_p / 100.0
		
		
		# Target is 0 if not enabled
		if not self.enabled:
			target_p = 0.0
			
		elif self.allow_reverse and self.reverse:
			# Negative target if in reverse and bidirectional
			target_p = 0.0 - target_p
		
			
		# Alarm stuff
		self.check_rev_alarm(target_p)
		
	
		
		
		# difference between target rate and current position
		# can be positive or negative
		delta_p = target_p - self.position
		
		dir = 1
		if delta_p < 0.0:
			dir = -1
			delta_p = abs(delta_p)
			
		
		# The delta_p we'll achieve if we start stopping now
		# dP = (Vt^2 - Vc^2) / 2A
		# Always positive
		min_delta_p = (self.velocity * self.velocity) / (2 * self.max_a)
				
		
		### Determine Target Velocity ###
		
		if delta_p > min_delta_p:

			target_v = dir * self.max_v
			#self.acceleration = dir * self.max_a
		
		else:
			# Limit velocity to prevent overshoot
			target_v = 0.0
			#self.acceleration = dir * (0.0 - self.max_a)
			
		
		
		
		### Determine Velocity ###
		delta_v = target_v - self.velocity
		
		if abs(delta_v) > abs(self.max_a * time_dif):
			delta_v = (delta_v/abs(delta_v)) * self.max_a * time_dif
		
		
		self.velocity += delta_v
		
		self.velocity = self.clamp(self.velocity, 0.0-self.max_v, self.max_v)
		
		
		### Determine Position ###
		
		self.position += self.velocity * time_dif
		
		
		if not self.allow_reverse:
			self.position = self.clamp(self.position, 0.0, self.max_p)
		else:
			self.position = self.clamp(self.position, -self.max_p, self.max_p)
	
	

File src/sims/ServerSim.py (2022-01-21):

#!/usr/bin/env python
#
# IP: HILICS
#
# Licensed under the Apache License, Version 2.0 (the "License");
# you may not use this file except in compliance with the License.
# You may obtain a copy of the License at
# 
#     http://www.apache.org/licenses/LICENSE-2.0
# 
# Unless required by applicable law or agreed to in writing, software
# distributed under the License is distributed on an "AS IS" BASIS,
# WITHOUT WARRANTIES OR CONDITIONS OF ANY KIND, either express or implied.
# See the License for the specific language governing permissions and
# limitations under the License.

import time
from random import random

from sims.SimIO import SimIO
from sims.AcceleratingActuatorSim import AcceleratingActuatorSim
from sims.MicroLogixComm import MicroLogixComm


##### IO List #####
##
## Analog Inputs (2 max)
##		Temperature
##		Humidity
##
## Analog Outputs (4 max)
## 		Damper - Controls temperature
##		Pump(?) - Controls humidity
## 		
## Digital Inputs (10 max)
##		Door open/closed
##		Locked/Unlocked
##		Lights on/off
## 		Motion (for alarm and/or unlocking door from inside - fire code)
##		Fire
##		Additional overheat sensor??
##		
## Digital outputs (6 max)
##		Lights
##		Door unlock
##		Intrusion alarm
##		Fire alarm
##		Fire supression (gas?)
## 		
##
## NOTE: Additional "network" sensors can be provided - the RPI can send the value to the PLC via Ethernet
##
##


### Class for calculating the current temperature and heat dissapated
### by a temperature zone
###
class Zone:

	def __init__(self, ac_btu, wall_area_ft2, cubic_feet):
		# Start around 23°C
		self.temp_c = 20.0 + (random() * 6.0)
		self.temp_f = (self.temp_c * 9.0 / 5.0) + 32.0

		self.wall_area_ft2 = wall_area_ft2

		# 1 m^2 = 10.7639 ft^2
		#self.wall_area_m2  = wall_area_ft2 / 10.7639

		# 1 m^3 = 35.315 ft^3
		self.volume_m3 = cubic_feet / 35.315
		
		# Density of air (kg/m3) * volume (m3)
		self.mass_kg = 1.2466 * self.volume_m3

		# W = J/s
		self.ac_watts = ac_btu * 0.293


	###
	###	ac_percent = 0 to 100
	###
	###
	def update(self, delta_t_s, ac_percent, outside_temp_f, extra_in_btu=0.0):
		# http://www.sensiblehouse.org/nrg_heatloss.htm
		#	Simplified heat loss
		#		BTU/hr = Area * U (insulation const) * delta_temp
		#
		
		#
		# Power:
		# 		1 BTU/hr is equal to 0.293 watts
		# Energy:
		#		1 Watt = 1 Joule/s
		# 
		# Heat:
		# 		Energy (Joules) = specific heat capacity of substance x mass of substance x temperature difference
		#		Approximate values:
		#			Specific heat capacity of air is 1012 J/kgC
		#			density of air is 1.2466 kg/m3
		#			mass (kg) = density (kg/m3) x volume (m3)
		#
		#			
		#

		# Energy: from Environment (19353.475935951843W), extra (0.0W), ac_out (81676.68W)
		# Energy: from Environment (-90.1108668436654W), extra (7725.805247999997W), ac_out (8790.0W)

		# Heat loss formula converted to watts
		# Units for this formula are in ft and °F
		# Assume U = 0.2 (lots of windows) - the bigger this number, the more impact the outside temp has
		from_environment_w = 0.293 * self.wall_area_ft2 * 0.2 * (outside_temp_f - self.temp_f)

		# Energy in from outside (may be negative or positive)
		from_environment_j = delta_t_s * from_environment_w
		
		extra_in_w = 0.293 * extra_in_btu
		extra_in_j = delta_t_s * extra_in_w

		# Energy taken out by AC unit
		ac_out_w = self.ac_watts * ac_percent / 100.0
		ac_out_j = delta_t_s * ac_out_w
		
		energy_j = (from_environment_j + extra_in_j) - ac_out_j

		delta_t_c = energy_j / (1012.0 * self.mass_kg)


		# Subtract since we're cooling
		self.temp_c += delta_t_c
		self.temp_f = (self.temp_c * 9.0 / 5.0) + 32.0
	
		print(f'DeltaT_C ({delta_t_c}), Temp ({self.temp_f}°F), Total ({energy_j}J), From Environment ({from_environment_w}W), extra ({extra_in_w}W), ac_out ({ac_out_w}W)')


### Class for calculating the status and amount of heat generated by each server
###
class Server:

	def __init__(self):
		
		# The status will determine the percentage of heat
		# generated by the server
		self.RUNNING = 1.0
		self.THROTTLED = 0.75
		self.SHUTDOWN = 0.0
		
		# Estimate based on:
		# https://www.enviromon.net/advanced-server-btu-calculator/
		self.btu_p_hr = 1883.424

		self.status = self.RUNNING
		self.thresh = 90.0 + random() * 20.0
	

	def update(self, temp):
		if temp < self.thresh:
			self.status = self.RUNNING
		elif temp < self.thresh + 10:
			self.status = self.THROTTLED
		else:
			self.status = self.SHUTDOWN


	def get_btu_p_hr(self):
		return self.status * self.btu_p_hr
	




class ServerSim:


	# pin_map[channel] = gpio_index

	#def __init__(self, addr, is_output, pin_map):
	def __init__(self):
		
		# update values  10x per second
		self.mlupdateperiod = 0.1

		self.mlcomm = MicroLogixComm()
		self.mlcomm.connect()
		self.mlcomm.test_connection()

		self.BLDG_EXTRA_BTU = 50000
		self.building_ac_percent = 100.0

		self.server_rm_ac_percent = 100.0

		self.num_servers = 14
		self.servers = []

		for i in range(self.num_servers):
			self.servers.append(Server())


		# Estimated BTU/hr based on https://www.calculator.net/btu-calculator.html
		# Then reduced to get a reasonable minimum temperature
		#
		# Assume a square 100' by 100' building with 10' ceiling
		# volume - 100,000 cubic ft
		# wall surface area = 24000 sq ft  (4 walls + ceiling + floor)

		self.building = Zone(237000.0, 24000.0, 100000.0)

		# BTU estimate based on:
		# https://www.enviromon.net/advanced-server-btu-calculator/
		self.server_room = Zone(29000.0, 600.0, 1000.0)

		self.simio = SimIO()
		self.last_update = 0
		self.time_scale = 1.0
		
		# I:0/0
		self.z0_damper = AcceleratingActuatorSim(100.0, 50.0, 50.0)

		# I:0/1
		self.z0_reheat = AcceleratingActuatorSim(10.0, 2.0, 1.0)
		
		# I:0/0
		self.z0_temp = 0.0
		# I:0/1
		self.z0_humidity = 0.0

		# O:0/0
		self.relay_out_0 = 0
		# O:0/1
		self.relay_out_1 = 0
		# O:0/2
		self.relay_out_2 = 0
		# O:0/3
		self.relay_out_3 = 0
		# O:0/4
		self.relay_out_4 = 0
		# O:0/5
		self.relay_out_5 = 0
		
		
		# I:0/0
		self.dig_in_0 = 0
		# I:0/1
		self.dig_in_1 = 0
		# I:0/2
		self.dig_in_2 = 0
		# I:0/3
		self.dig_in_3 = 0
		# I:0/4
		self.dig_in_4 = 0
		# I:0/5
		self.dig_in_5 = 0
		# I:0/6
		self.dig_in_6 = 0
		
		
		# Project Select for Demo:
		# I:0/7 - I:0/9
		self.proj0 = 0
		self.proj1 = 0
		self.proj2 = 1
		
		
		# I:0.4
		self.analog_in_0 = 0.0
		# I:0.5
		self.analog_in_1 = 0.0


		
	
	
	
	def close(self):
		self.simio.close()
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

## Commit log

2021-06-17 Fixed bug that broke pump and valve in tank sim
2021-07-15 Fixed a threading bug
2021-11-19 Comm class for network sensors/actuators
2021-12-17 Refactored SimIO and start linking up sensors/actuators

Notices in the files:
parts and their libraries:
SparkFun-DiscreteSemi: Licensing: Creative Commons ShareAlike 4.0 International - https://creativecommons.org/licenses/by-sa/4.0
